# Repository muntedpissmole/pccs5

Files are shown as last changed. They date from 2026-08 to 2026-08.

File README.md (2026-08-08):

# The Pissmole Camper Control System

PCCS is a software and hardware solution for control of electrics and home automation in a caravan or camper trailer. It replaces a typical switch panel and gauges like water and battery levels with a modern touchscreen UI that provides control of dimmable lighting, one-touch activation of lighting scenes and automatic triggering of lights based on sunset/sunrise times and door or panel open and closes. The software runs on a Raspberry Pi 4 or 5. A PCB design for ordering the PCCS Core circuit board and 3D printable mount is provided in the `/kicad` folder.

Important information is displayed at a glance (full list and screenshots below). Internet can be distributed from a USB/Wi-Fi hotspot or Starlink through a downstream WAP. Networking services - NAT, DNS, DHCP and ad-filtering are provided by nftables and Pi-Hole. Instructions are provided for installing the UniFi OS server for management of WAP points if desired.

The UI is accessible from any device connected to the WiFi and can also be accessed remotely via something like a Cloudflare tunnel.

## Getting started

Start with [Wiring and Hardware](https://github.com/muntedpissmole/pccs5/wiki/Wiring-and-Hardware) to fabricate, mount and wire the PCCS Core PCB, then see [Software Installation](https://github.com/muntedpissmole/pccs5/wiki/Software-Installation) to install the PCCS via the guided installer.

Full instructions are in the [project wiki](https://github.com/muntedpissmole/pccs5/wiki/).

## System overview

A touchscreen in the kitchen or similar area shows the main user interface and is also reachable from phones or tablets on the LAN:

- Dimmable lighting sliders with red/white anti-bug mode and on/off buttons for non-dimmable loads (water, lighting, fridge circuits)
- Ambient lights that fade on as it gets dark
- One-touch lighting scenes
- Control of Sonos speakers
- Light/dark UI themes and an extensive settings page

## Display of Environmental information

- Water tank level
- Current temperature and fridge/freezer temperatures
- Current battery charge, voltage, current consumption, estimated power remaining and current/daily solar generation
- GPS coordinates, closest suburb, altitude, satellite quality, sunrise/sunset, and the day/evening/night timing that drives automation
- 4 Day weather forecast, humidity and expected overnight temperature if Internet is present
- Internet connection quality details
- What lights are on and what doors or panels are open
- Health status of connected hardware modules like solar or GPS

## Hardware architecture

- Raspberry Pi 4/5
- Dual ESP32-S3s for 16 channels of PWM dimming via MOSFETs
- u-blox NEO-M9N GPS for location data
- Victron SmartShunt and SmartSolar support for battery and solar monitoring
- WS281X addressable LED strip outputs
- 10A relays for non-dimmable loads like lighting circuits, floodlights and water pumps
- Reed switch inputs for door/panel sensing and triggering of lights
- 1-Wire bus for temperature sensors
- Water tank level sensor input
- Spare channels for everything for expansion

### PCCS Core

<table>
  <tr>
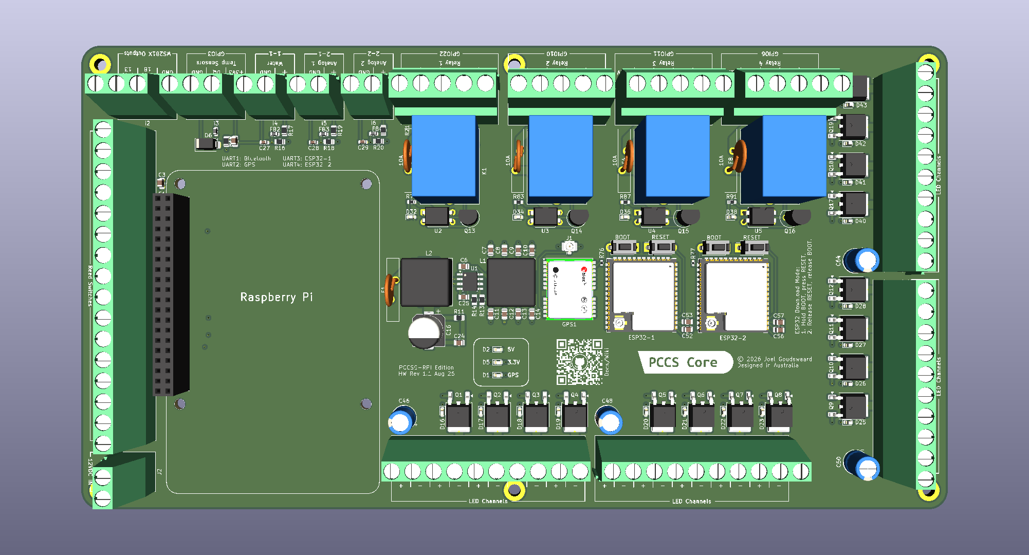
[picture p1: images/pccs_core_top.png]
PCCS Core — top, bare board
    <td align="center" width="50%"></td>
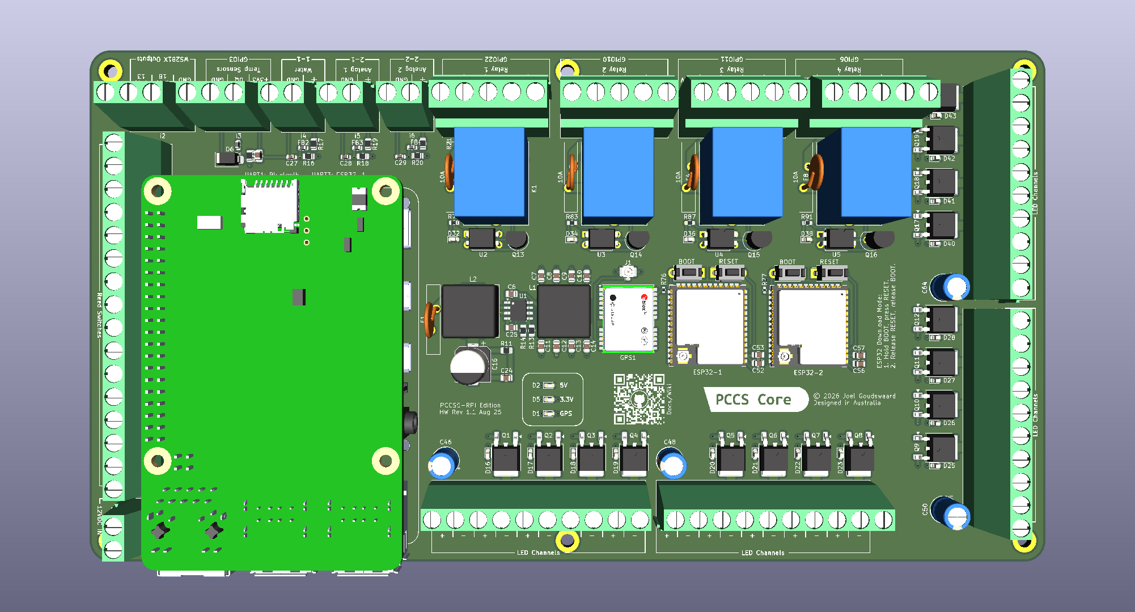
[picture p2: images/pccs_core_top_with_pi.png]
PCCS Core — top, with Raspberry Pi fitted
    <td align="center" width="50%"></td>
  </tr>
  <tr>
    <td align="center"><strong>Top (bare board)</strong></td>
    <td align="center"><strong>Top (with Raspberry Pi fitted)</strong></td>
  </tr>
  <tr>
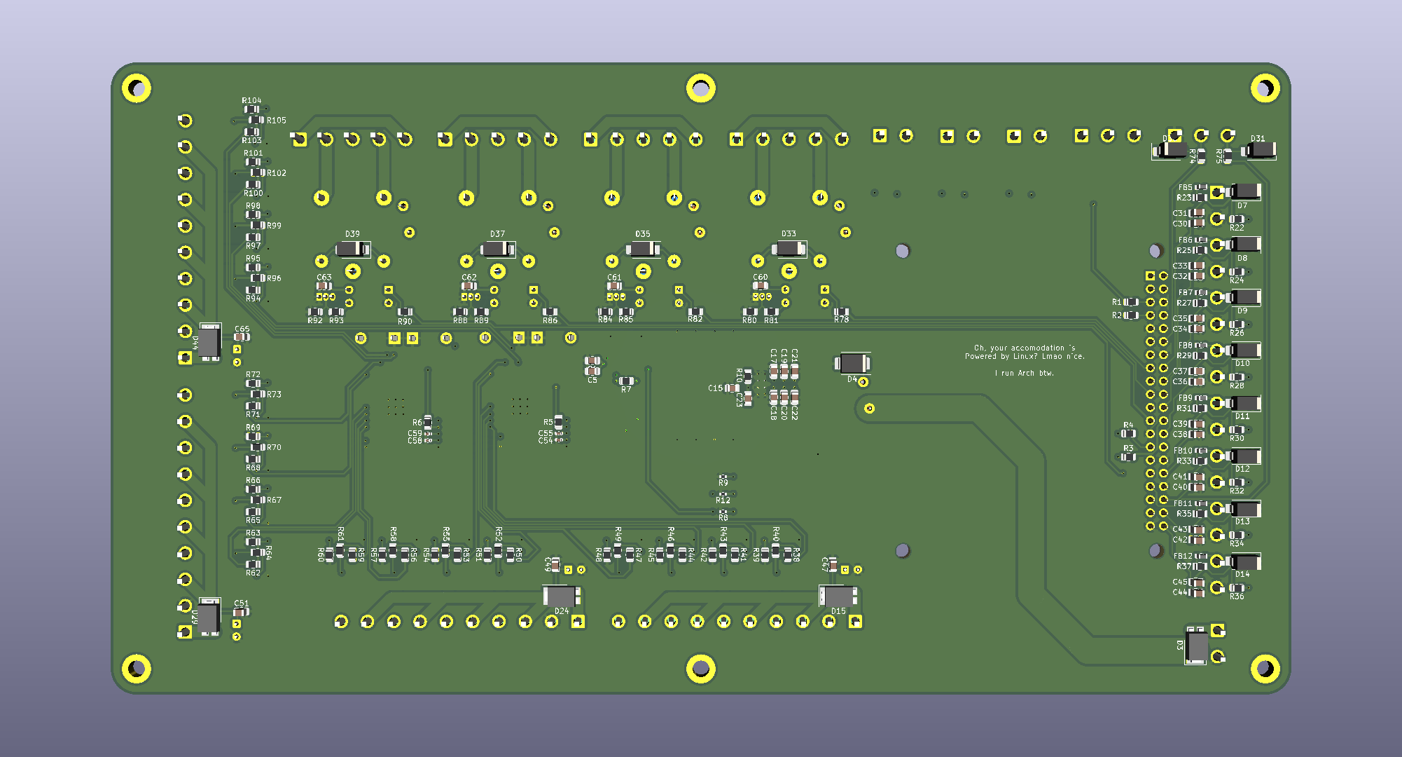
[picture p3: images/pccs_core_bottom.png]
PCCS Core — bottom
    <td align="center"></td>
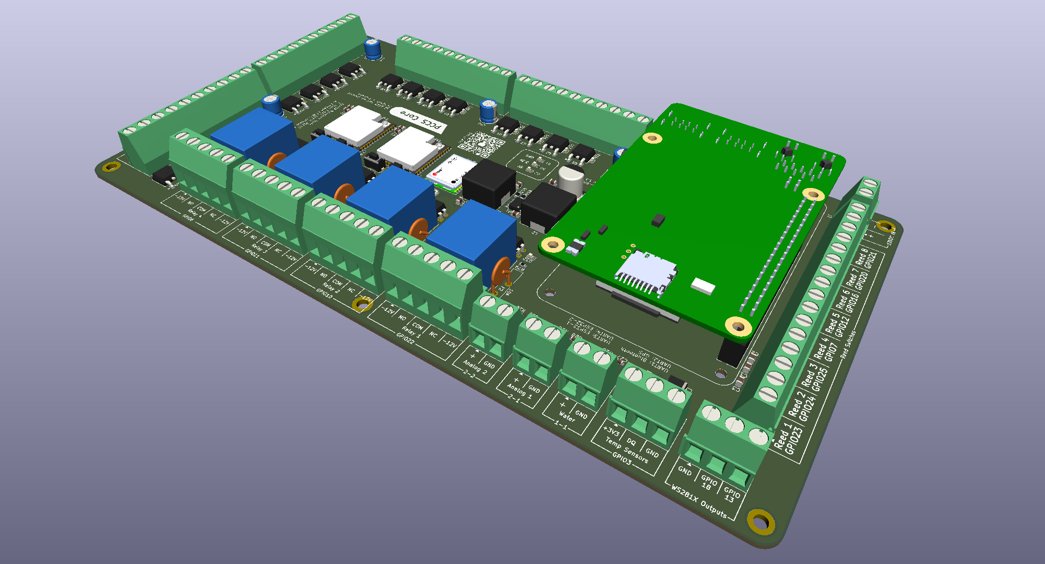
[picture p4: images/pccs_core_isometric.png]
PCCS Core — isometric view with Raspberry Pi fitted
    <td align="center"></td>
  </tr>
  <tr>
    <td align="center"><strong>Bottom</strong></td>
    <td align="center"><strong>Isometric (with Raspberry Pi fitted)</strong></td>
  </tr>
</table>

## User interface

The UI runs on touchscreens, tablets, and phones.

<table>
  <tr>
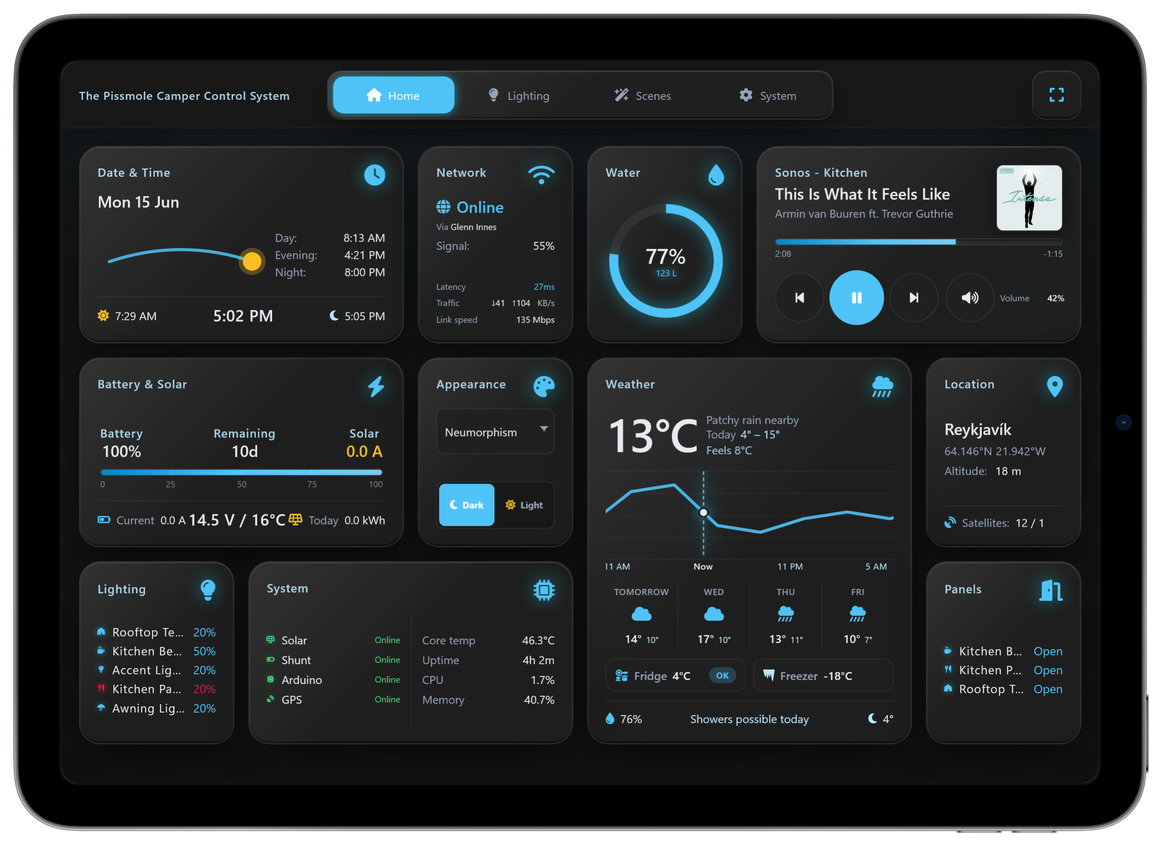
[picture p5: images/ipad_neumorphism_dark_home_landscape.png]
Neumorphism dark — iPad landscape
    <td align="center"></td>
  </tr>
  <tr>
    <td align="center"><strong>Neumorphism (Dark)</strong></td>
  </tr>
  <tr>
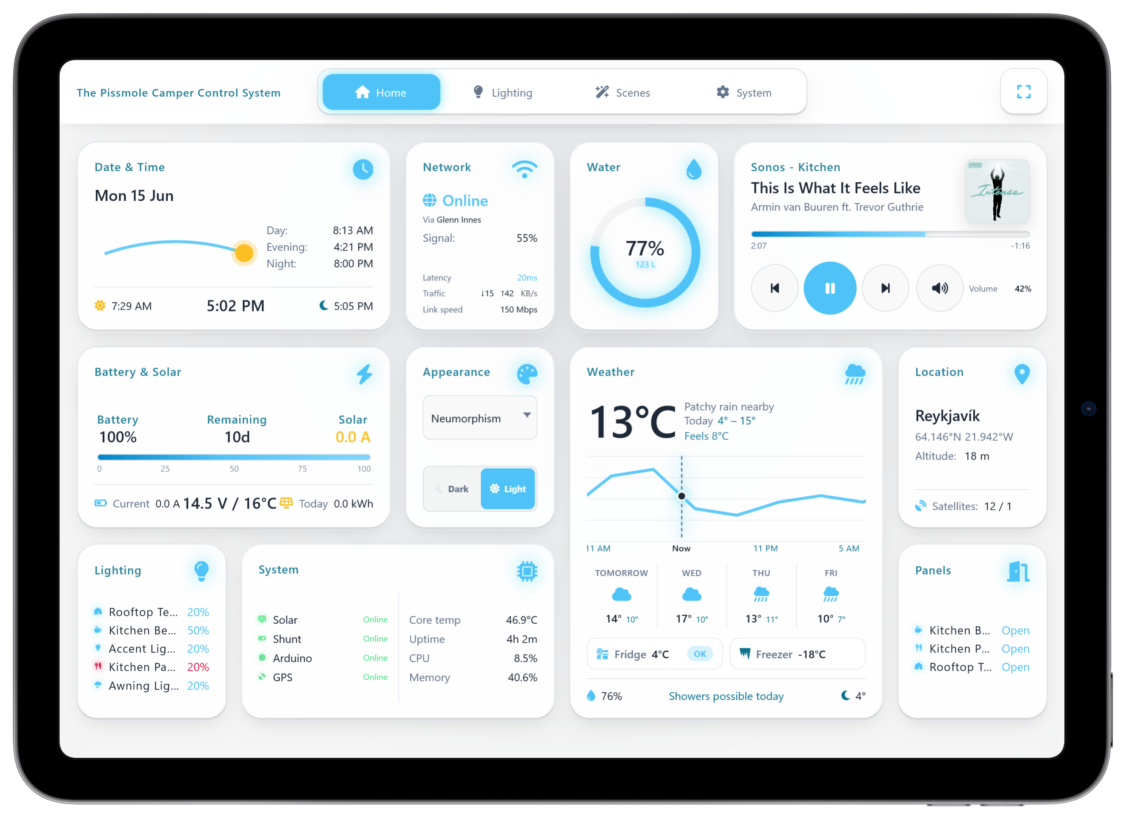
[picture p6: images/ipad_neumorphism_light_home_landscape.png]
Neumorphism light — iPad landscape
    <td align="center"></td>
  </tr>
  <tr>
    <td align="center"><strong>Neumorphism (Light)</strong></td>
  </tr>
  <tr>
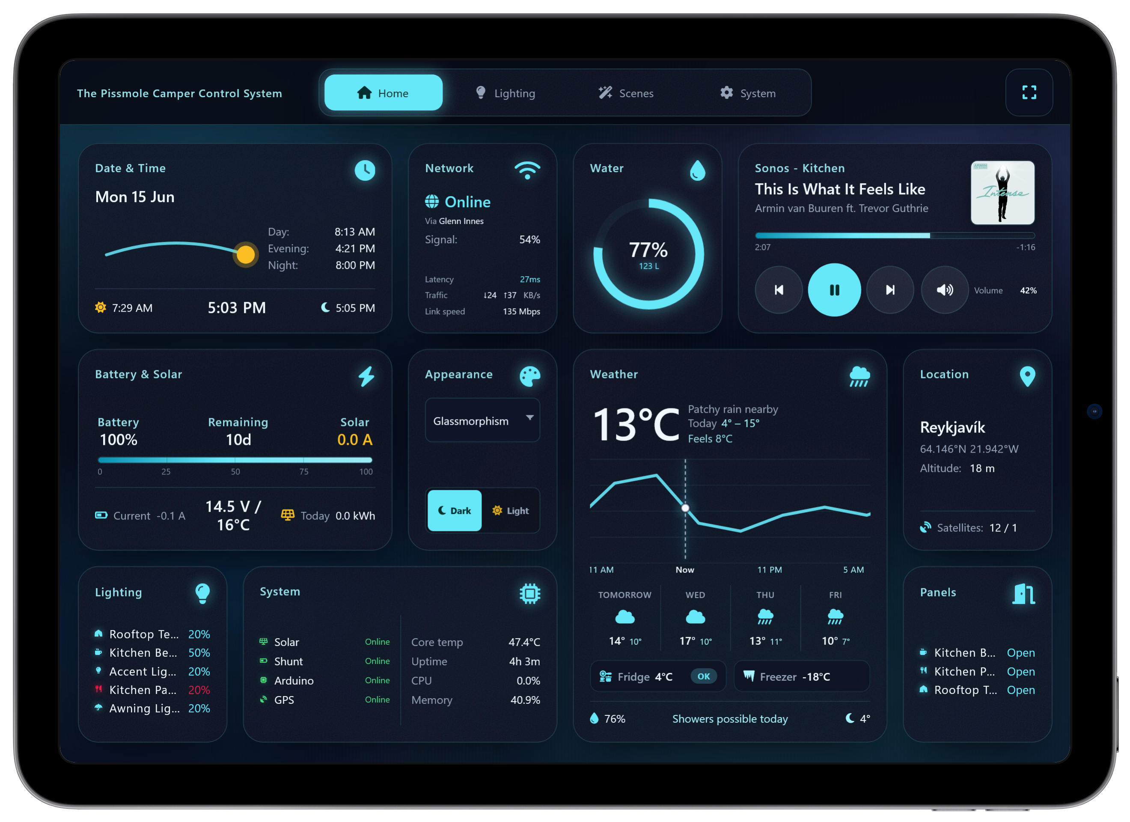
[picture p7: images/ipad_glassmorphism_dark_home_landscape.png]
Glassmorphism dark — iPad landscape
    <td align="center"></td>
  </tr>
  <tr>
    <td align="center"><strong>Glassmorphism (Dark)</strong></td>
  </tr>
  <tr>
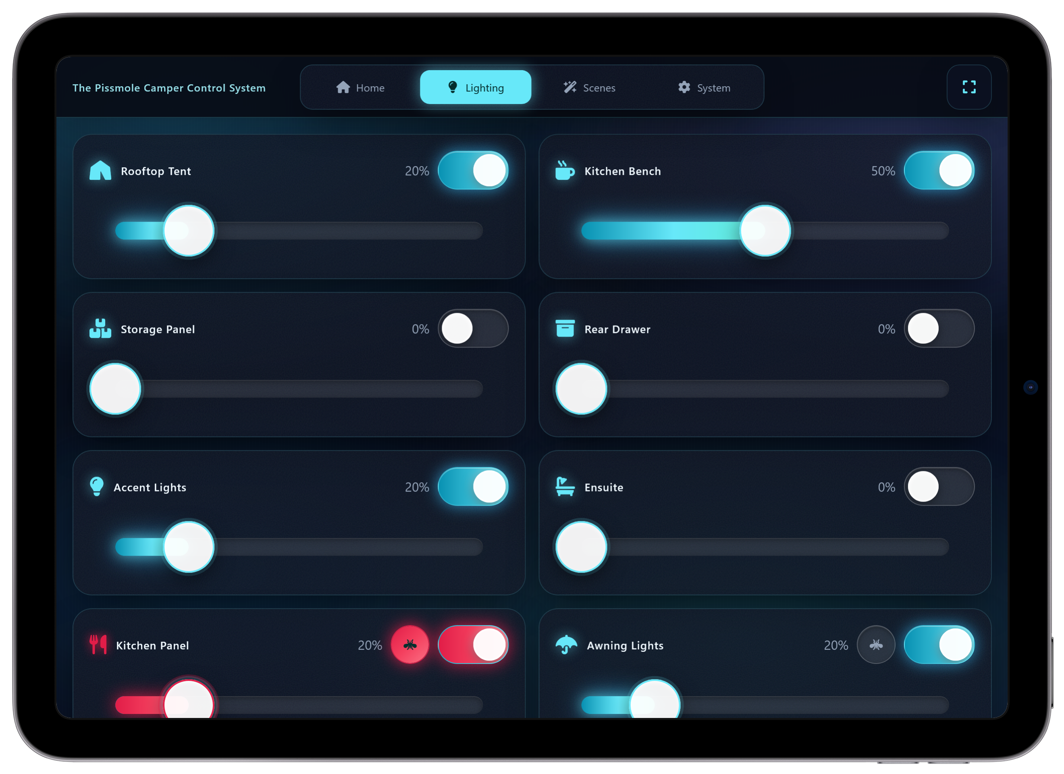
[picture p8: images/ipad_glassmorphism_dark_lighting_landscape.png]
Glassmorphism dark — iPad lighting
    <td align="center"></td>
  </tr>
  <tr>
    <td align="center"><strong>Glassmorphism (Dark) — Lighting</strong></td>
  </tr>
</table>

<table>
  <tr>
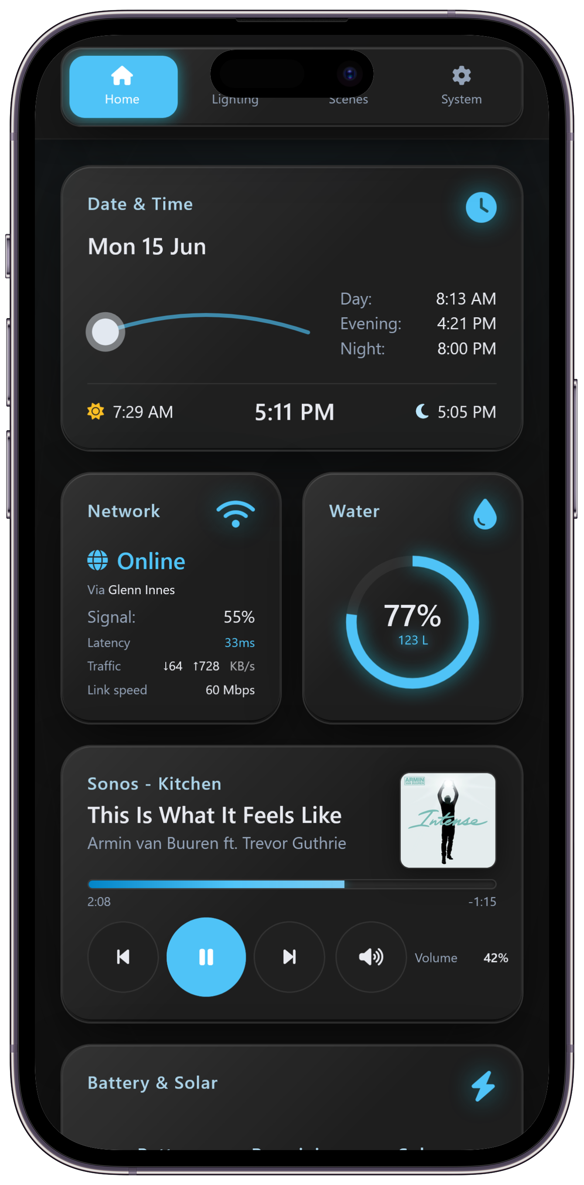
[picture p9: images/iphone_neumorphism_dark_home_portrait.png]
Neumorphism dark — iPhone portrait
    <td align="center" width="50%"></td>
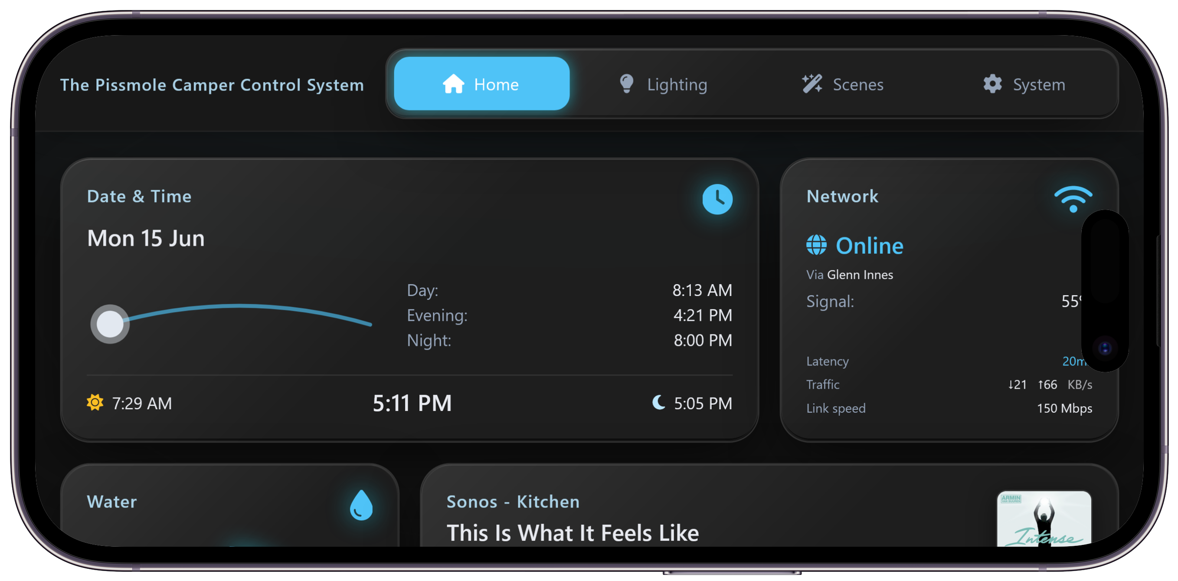
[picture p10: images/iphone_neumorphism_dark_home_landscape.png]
Neumorphism dark — iPhone landscape
    <td align="center" width="50%"></td>
  </tr>
  <tr>
    <td align="center"><strong>Neumorphism (Dark) — iPhone Portrait</strong></td>
    <td align="center"><strong>Neumorphism (Dark) — iPhone Landscape</strong></td>
  </tr>
</table>

<details>
<summary><h3>Additional themes (click to expand)</h3></summary>

<table>
  <tr>
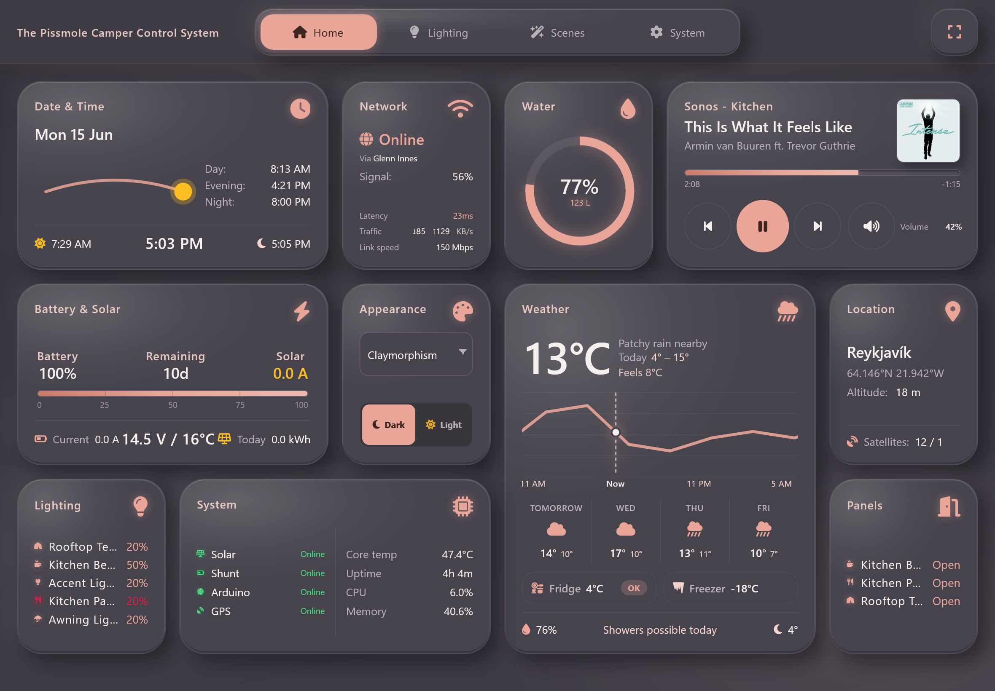
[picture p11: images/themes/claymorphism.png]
Claymorphism
    <td align="center" width="50%"></td>
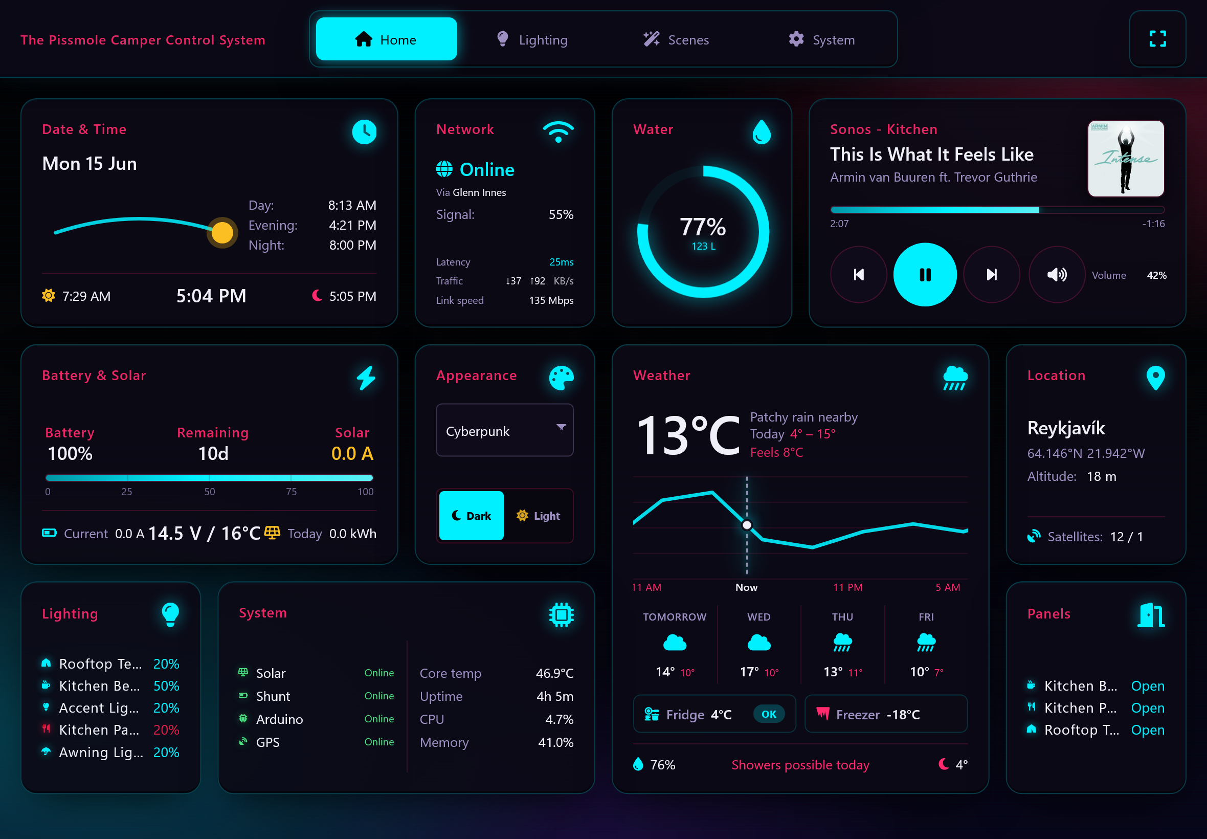
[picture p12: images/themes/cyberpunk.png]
Cyberpunk
    <td align="center" width="50%"></td>
  </tr>
  <tr>
    <td align="center"><strong>Claymorphism</strong><br></td>
    <td align="center"><strong>Cyberpunk</strong><br></td>
  </tr>
  <tr>
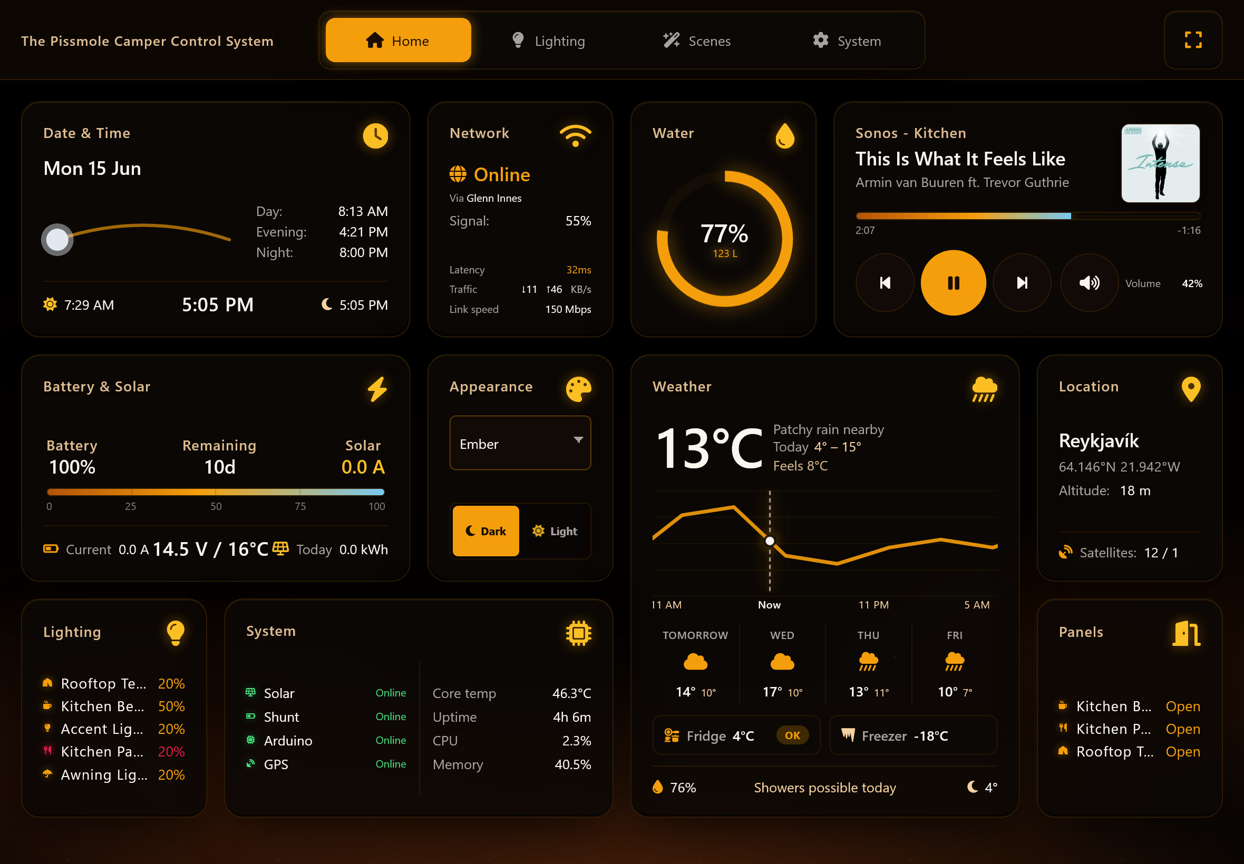
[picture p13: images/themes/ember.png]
Ember
    <td align="center"></td>
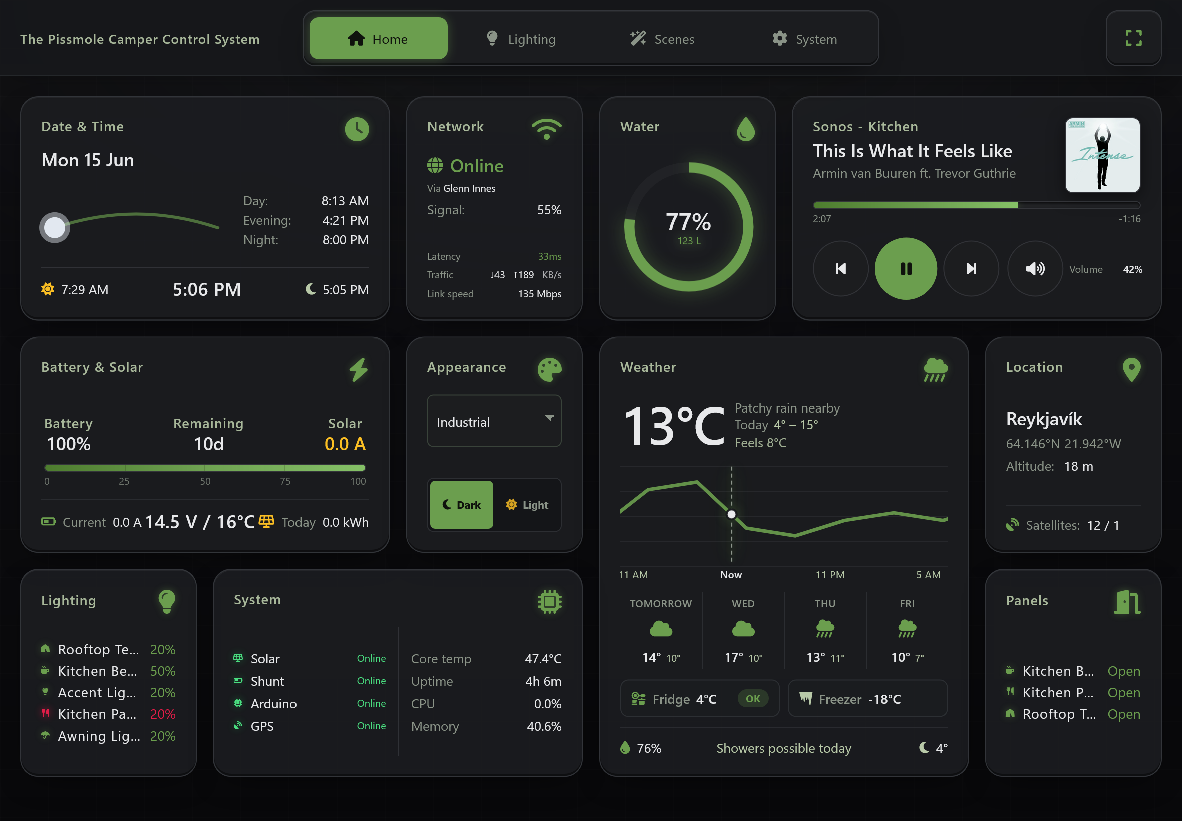
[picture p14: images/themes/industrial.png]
Industrial
    <td align="center"></td>
  </tr>
  <tr>
    <td align="center"><strong>Ember</strong><br></td>
    <td align="center"><strong>Industrial</strong><br></td>
  </tr>
  <tr>
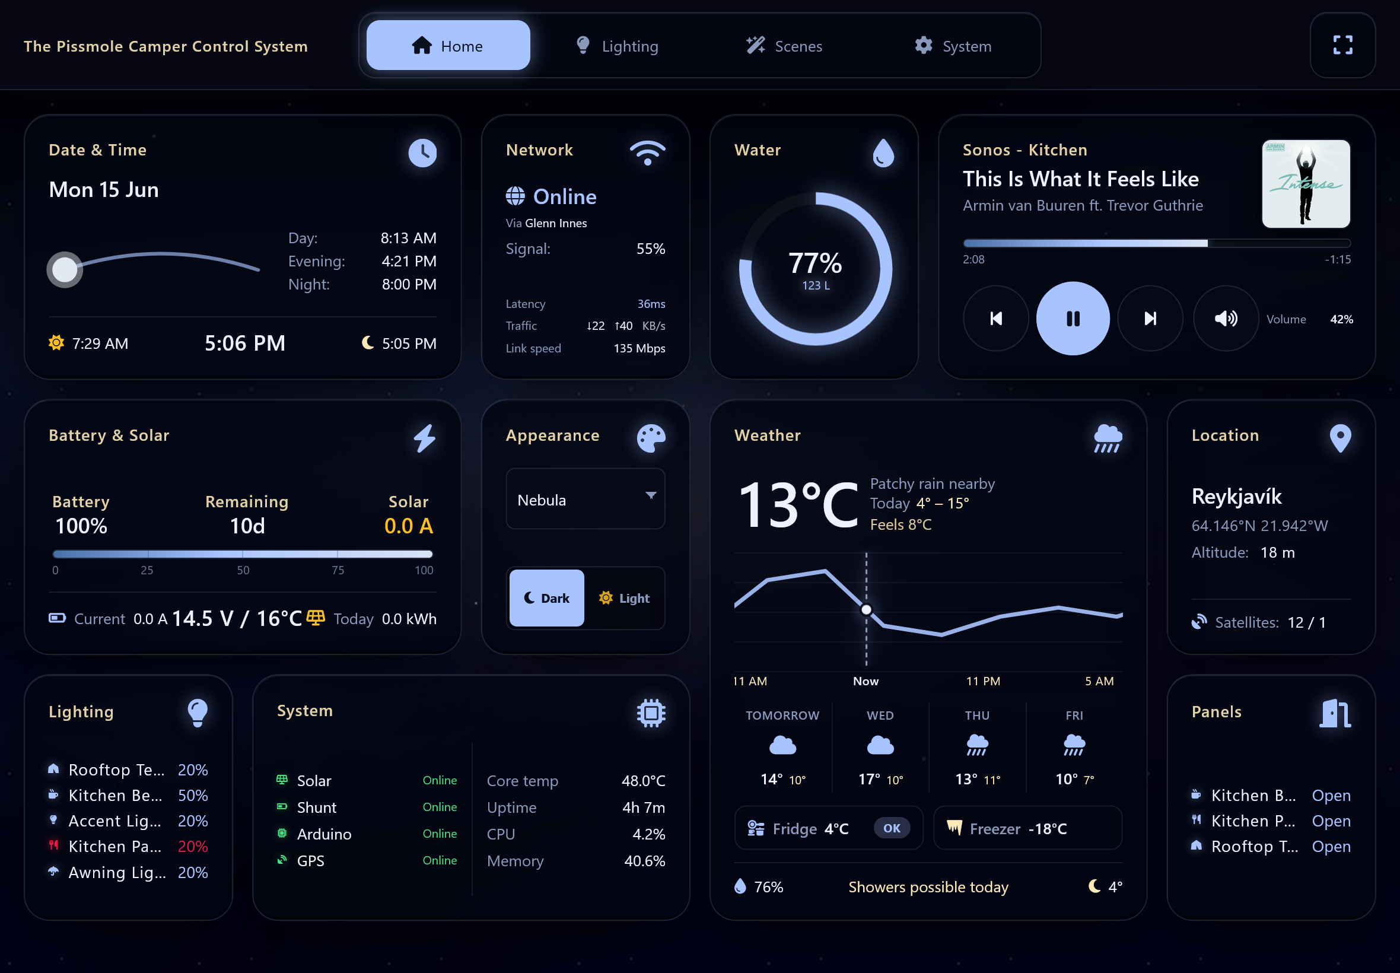
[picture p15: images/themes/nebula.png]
Nebula
    <td align="center"></td>
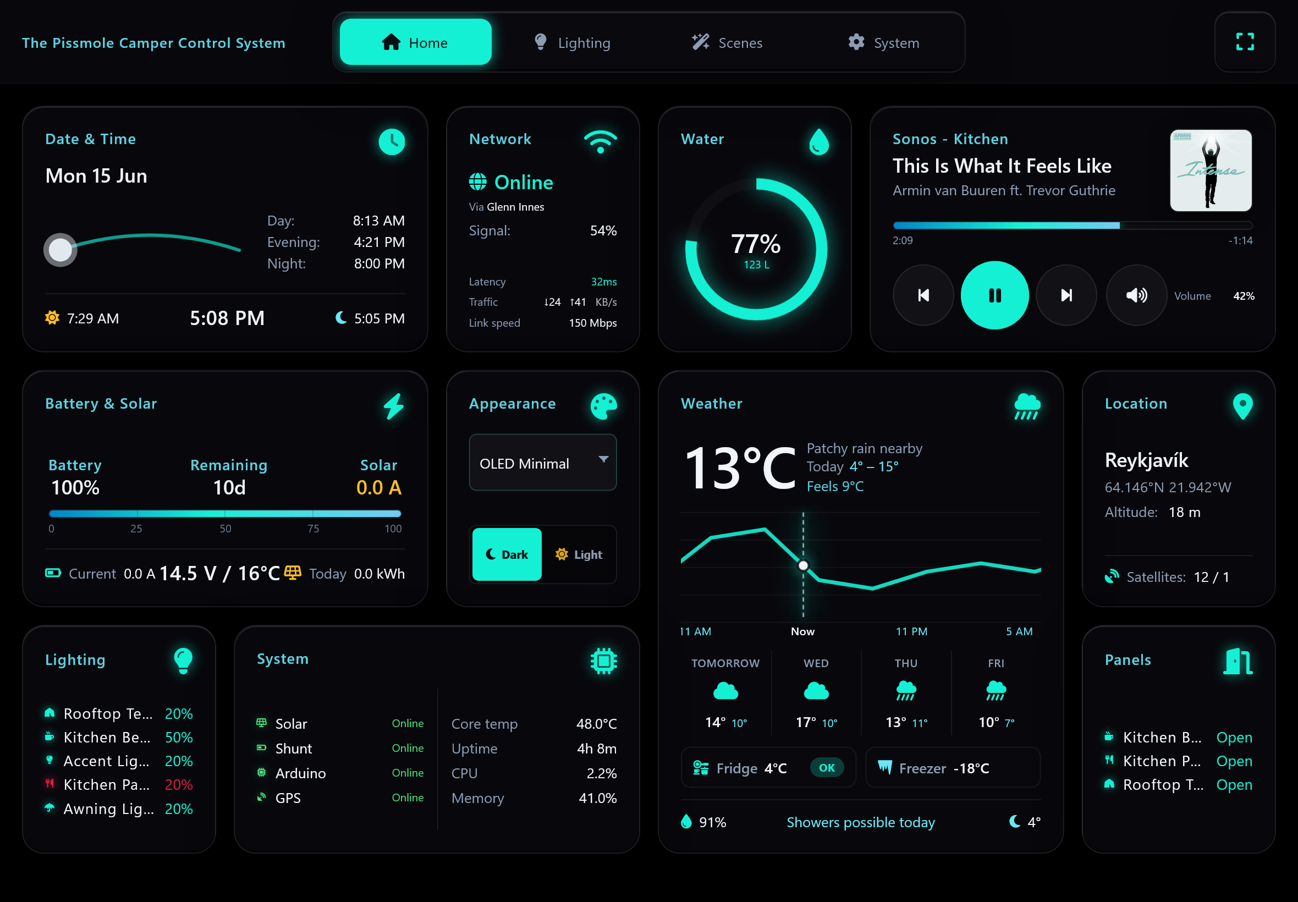
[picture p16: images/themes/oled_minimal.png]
OLED Minimal
    <td align="center"></td>
  </tr>
  <tr>
    <td align="center"><strong>Nebula</strong><br></td>
    <td align="center"><strong>OLED Minimal</strong><br></td>
  </tr>
  <tr>
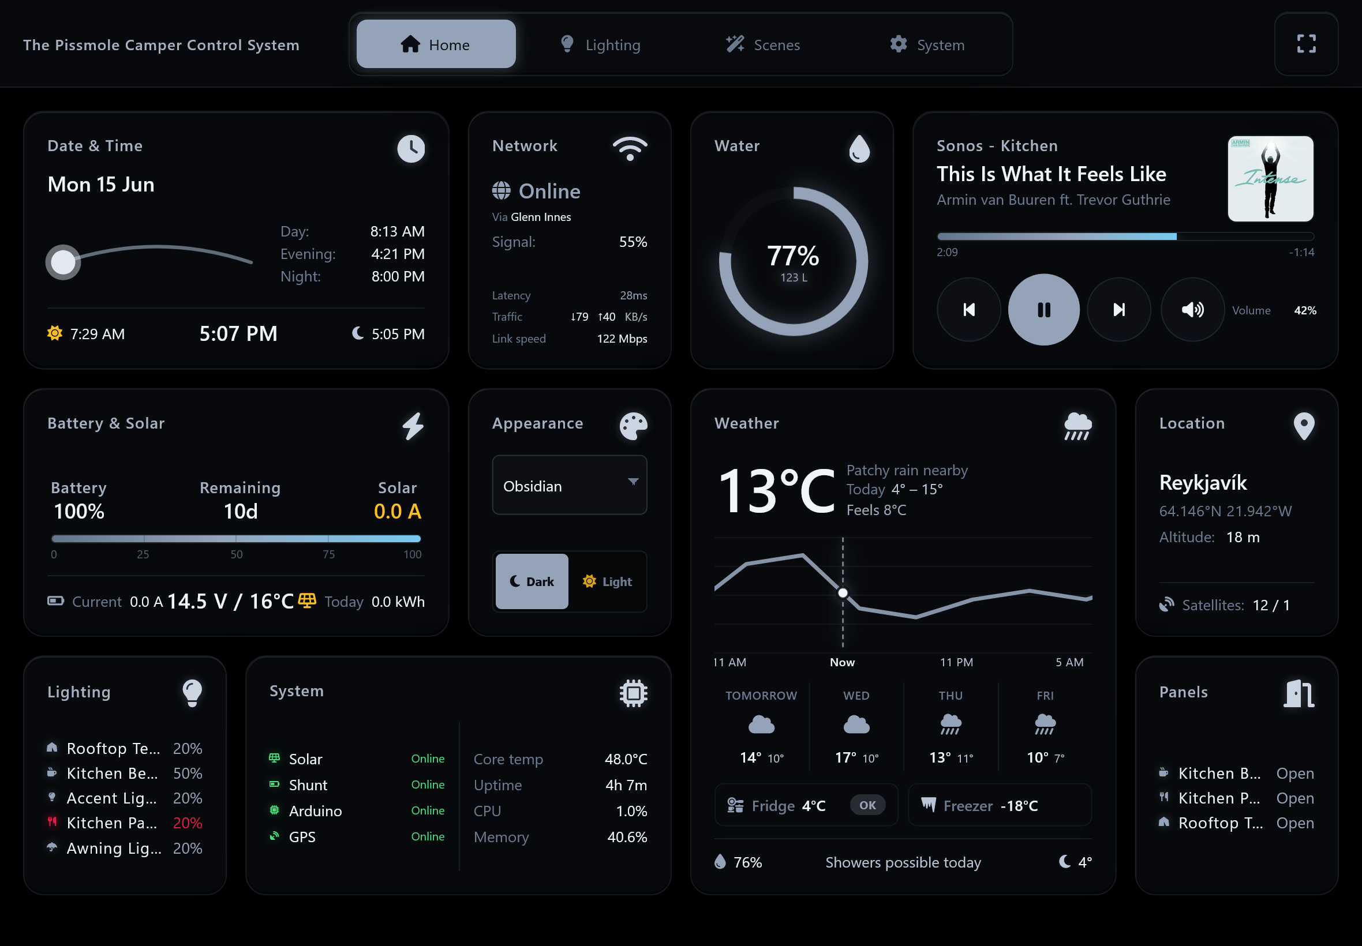
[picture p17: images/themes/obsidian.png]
Obsidian
    <td align="center"></td>
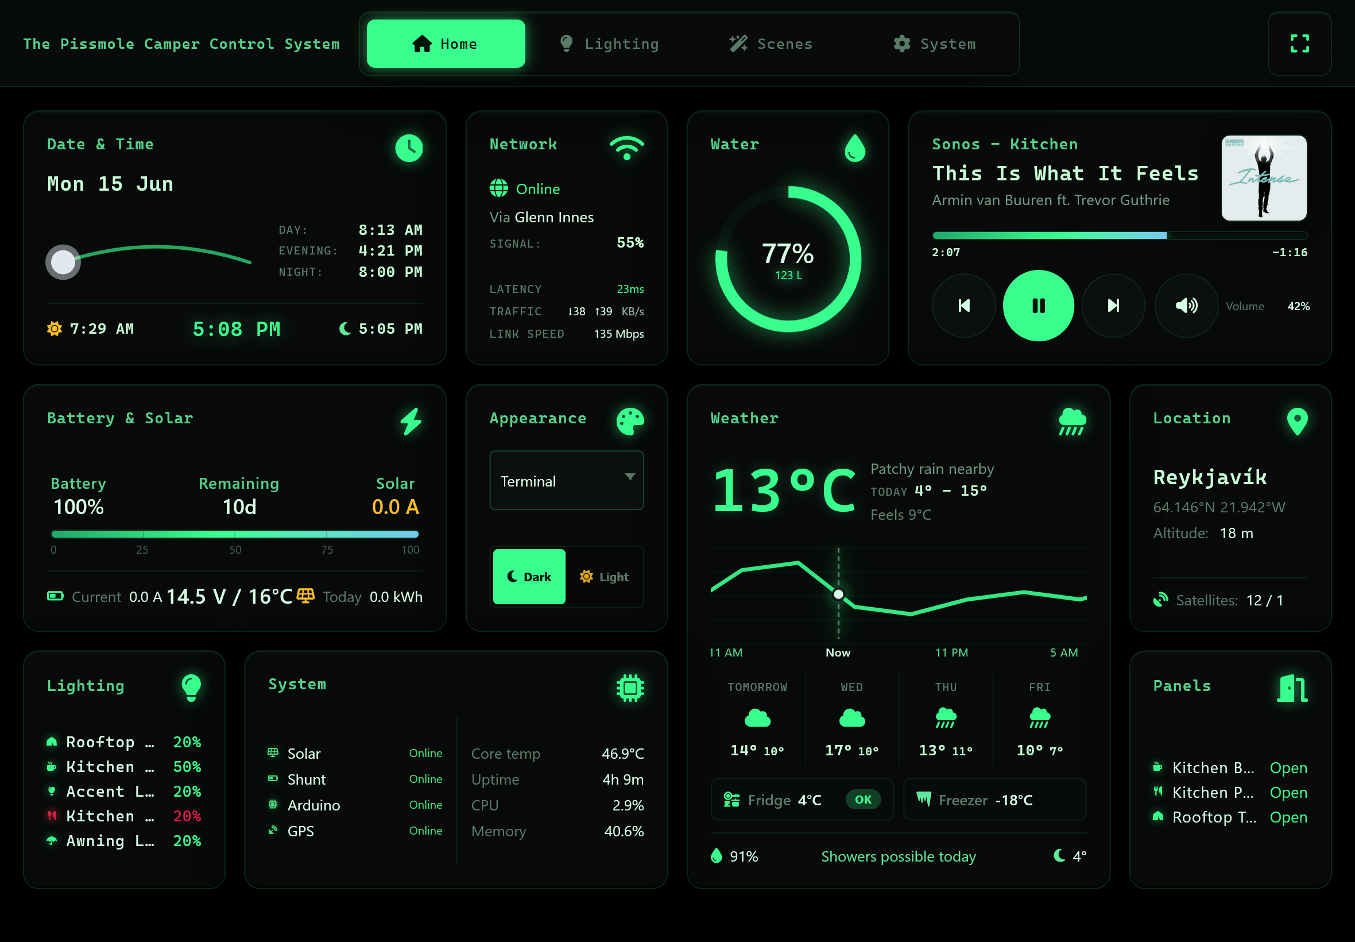
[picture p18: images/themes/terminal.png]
Terminal
    <td align="center"></td>
  </tr>
  <tr>
    <td align="center"><strong>Obsidian</strong><br></td>
    <td align="center"><strong>Terminal</strong><br></td>
  </tr>
  <tr>
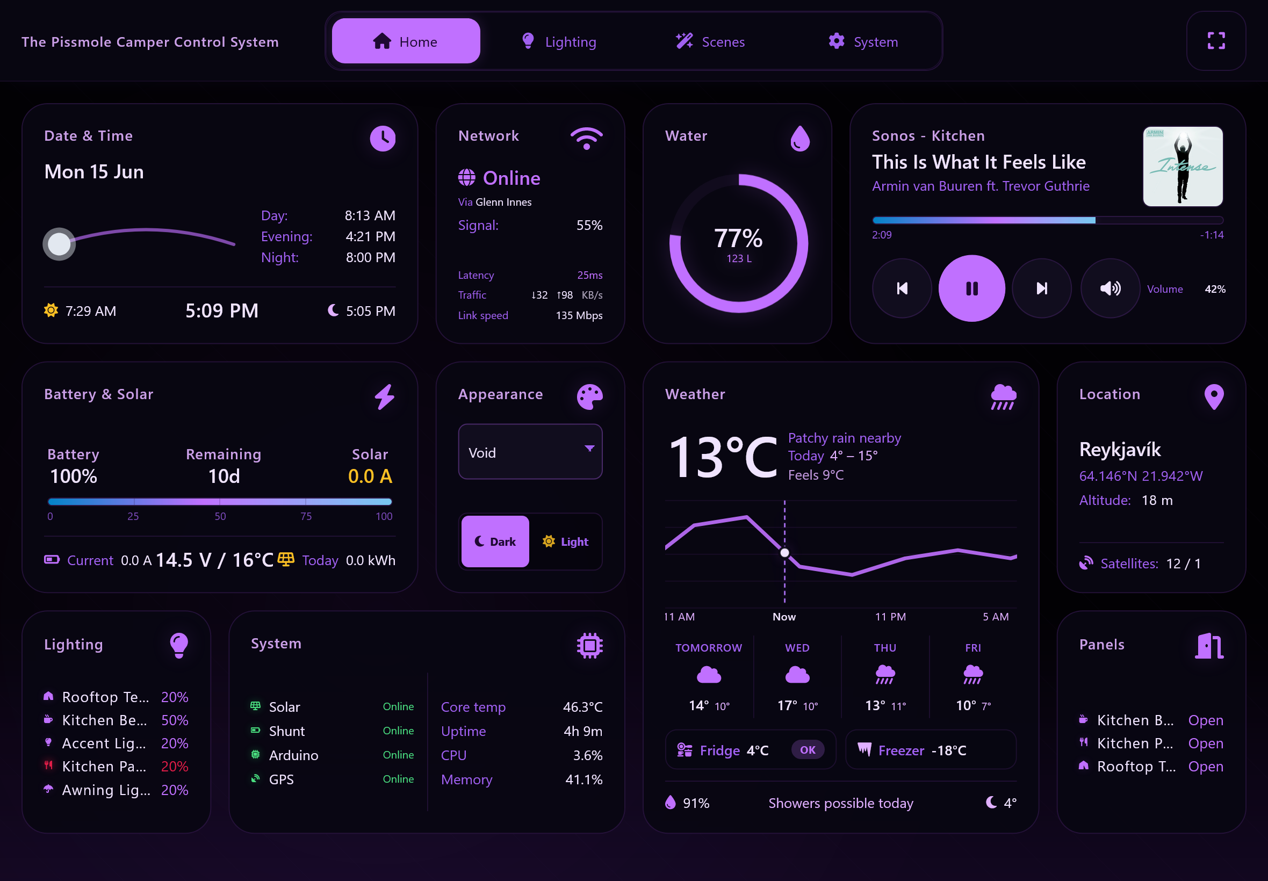
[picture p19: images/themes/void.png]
Void
    <td align="center" colspan="2"></td>
  </tr>
  <tr>
    <td align="center" colspan="2"><strong>Void</strong><br></td>
  </tr>
</table>

More examples in the [`/images`](images/) folder.

</details>

---

## Documentation

Wiring, installation, configuration, and optional packages are on the **[project wiki](https://github.com/muntedpissmole/pccs5/wiki)**.

| Topic | Wiki page |
|---|---|
| PCCS4 vs PCCS5 | [Differences between PCCS4 and PCCS5](https://github.com/muntedpissmole/pccs5/wiki/Differences-between-PCCS4-and-PCCS5) |
| Wiring and hardware | [Wiring and Hardware](https://github.com/muntedpissmole/pccs5/wiki/Wiring-and-Hardware) |
| Software Installation | [Software Installation](https://github.com/muntedpissmole/pccs5/wiki/Software-Installation) |
| Software Configuration | [Software Configuration](https://github.com/muntedpissmole/pccs5/wiki/Software-Configuration) |
| Victron setup | [Victron Setup](https://github.com/muntedpissmole/pccs5/wiki/Victron-Setup) |
| Toast system | [Toast System](https://github.com/muntedpissmole/pccs5/wiki/Toast-System) |
| UniFi OS Server | [UniFi OS Server](https://github.com/muntedpissmole/pccs5/wiki/UniFi-OS-Server) |
| Pi-hole | [Pi-hole](https://github.com/muntedpissmole/pccs5/wiki/Pi-hole) |

---

## License

Licensed under the [MIT License](LICENSE).

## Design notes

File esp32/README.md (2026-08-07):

# PCCS5 ESP32-S3 firmware

ESP32-S3-WROOM-1U firmware for the two lighting/analog MCUs.

Host protocol (UART1, 115200 8N1): `SET` / `RAMP` / `GET` / `ANALOG` / `GETVCC` / `GETALL`.

| Sketch | Role | Pi UART | ESP host UART | PWM GPIOs | Analog GPIOs |
|---|---|---|---|---|---|
| `esp32_1/` | ESP32-1 | `uart3` → `/dev/ttyAMA2` (Pi GPIO 4/5) | GPIO 17 RX / 18 TX | 4–11 | 1 (water) |
| `esp32_2/` | ESP32-2 | `uart4` → `/dev/ttyAMA3` (Pi GPIO 8/9) | GPIO 17 RX / 18 TX | 4–11 | 1, 2 |

Shared core: `PccsEspFirmware.h` (copied into each sketch folder).

## Build / flash

- Chip: **ESP32-S3** / **ESP32-S3-WROOM-1U**
- Upload over the module’s programming USB interface (not the Pi host UART)

```bash
arduino-cli core update-index
arduino-cli core install esp32:esp32

arduino-cli compile --fqbn esp32:esp32:esp32s3 esp32/esp32_1
arduino-cli upload -p /dev/ttyACM0 --fqbn esp32:esp32:esp32s3 esp32/esp32_1

arduino-cli compile --fqbn esp32:esp32:esp32s3 esp32/esp32_2
arduino-cli upload -p /dev/ttyACM0 --fqbn esp32:esp32:esp32s3 esp32/esp32_2
```

## ADC / water level

- 12-bit reads (0–4095), 64-sample average — matches `water_adc_max = 4095` on the Pi
- `GETVCC` returns `3300` (mV of the 3V3 rail for the 150 Ω pull-ups)
- Water sender on ESP32-1 GPIO 1: empty ~240 Ω, full ~33 Ω (`config/pccs.conf` `[sensors]`)

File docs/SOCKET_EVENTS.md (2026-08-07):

# PCCS5 Socket Event Contract

This document defines every Socket.IO event used by the lighting backend in this pass.

## Offline overlay

When Socket.IO disconnects (or fails to load), `#offline-overlay` appears after 800ms and blocks interaction until reconnect. Implemented in `offline-overlay.js` + `socket-client.js`.

## Client → Server

### `light_change`

User moved a dimmer slider or toggled a dimmer pill.

```json
{ "name": "kitchen_bench", "brightness": 65 }
```

RGB bug lights include mode:

```json
{ "name": "kitchen_panel", "brightness": 55, "mode": "red" }
```

- `name` must be in `compiled.light_names`
- `brightness` clamped 0–100 server-side
- `mode` only applied for RGB lights

**HTTP fallback:** `POST /api/light` with the same JSON body.

### `relay_change`

User toggled a relay control (socket only — no HTTP fallback).

```json
{ "name": "floodlights", "on": true }
```

Relays use `expires: manual` — they persist through scenes, reed changes, and phase changes until toggled again.

### `get_reeds`

Request effective reed states. Server replies with `reed_update`.

### `set_scene`

Activate a lighting scene (one-shot reconcile with ramp).

```json
{ "scene": "bedtime" }
```

**HTTP fallback:** `POST /api/scene` with the same JSON body.

### `force_phase`

Lock or clear phase override.

```json
{ "phase": "Evening" }
```

Clear: `{ "phase": null }`

### `force_reed`

Diagnostics override (also affects main UI effective states).

```json
{ "name": "rooftop_tent", "closed": true }
```

Clear force: `{ "name": "rooftop_tent", "closed": null }`

## Server → Client

### `lights_config`

Sent on `connect`. Ordered list of UI controls from `pccs.conf`:

```json
[
  { "name": "rooftop_tent", "label": "Rooftop Tent", "type": "dimmer", "icon": "fa-tent", "has_mode": false, "order": 10 }
]
```

`type` is `dimmer` or `relay`.

### `state_update`

Authoritative light/relay levels after reconcile.

```json
{
  "kitchen_bench": 65,
  "kitchen_panel": 55,
  "kitchen_panel_mode": "white",
  "floodlights": 1
}
```

- Dimmers: 0–100 integer brightness
- Relays: truthy/falsey on state
- RGB lights: `{name}_mode` key with `white` or `red`

### `reeds_config`

Sent on `connect`. Reed metadata for the system tile:

```json
[{ "name": "kitchen_panel", "label": "Kitchen Panel", "icon": "fa-utensils", "order": 10 }]
```

### `reed_update` (main UI)

Effective reed states — hardware merged with operator forces.

```json
{ "states": { "rooftop_tent": true, "kitchen_bench": false } }
```

`true` = closed (secure), `false` = open.

**Main UI rule:** clients must not guess forced vs raw. Use this event only.

### `reed_diag_update` (diagnostics — future tile)

Raw hardware + force metadata. Not consumed by the lighting tab yet.

```json
{
  "states": { "rooftop_tent": true },
  "forced": { "kitchen_bench": false }
}
```

### `phase_update` (main UI)

```json
{ "phase": "evening", "day_start": "06:12", "evening_start": "18:45", "night_start": "21:30" }
```

### `gps_update`

Full GPS telemetry from `modules/gps` (also drives home location tile).

```json
{
  "fix_quality": 2,
  "satellites": 9,
  "latitude": -37.191,
  "longitude": 145.711,
  "suburb": "Alexandra",
  "hardware_missing": false
}
```

### `sensor_update`

Water tank and 1-wire temperatures.

```json
{
  "water_percent": 68,
  "outside_temp_c": 12.4,
  "fridge_temp_c": null,
  "temp_valid": true
}
```

### `set_gps_simulation`

Diagnostics: force no-fix mode.

```json
{ "no_fix": true }
```

### `phase_diag_update` (diagnostics)

```json
{ "forced": false }
```

`forced: true` when operator has locked phase via diag controls.

## REST

| Route | Purpose |
|---|---|
| `POST /api/light` | HTTP fallback for `light_change` |
| `GET /api/scenes` | Scene list for Scenes tab |
| `POST /api/scene` | HTTP fallback for `set_scene` |
| `GET /api/reeds` | Reed labels/icons for system tile |
| `GET /api/explain` | Policy snapshot: sources, desired vs observed, drift |

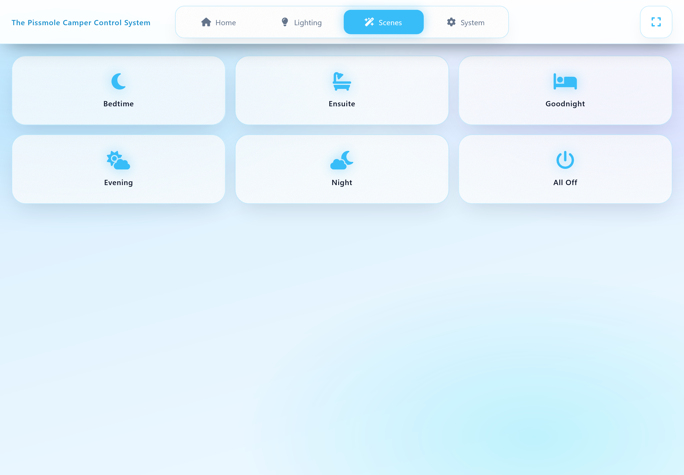
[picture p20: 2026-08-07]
images/themes/Glassmorphism/Screen Shot 2026-06-15 at 17.03.17.png

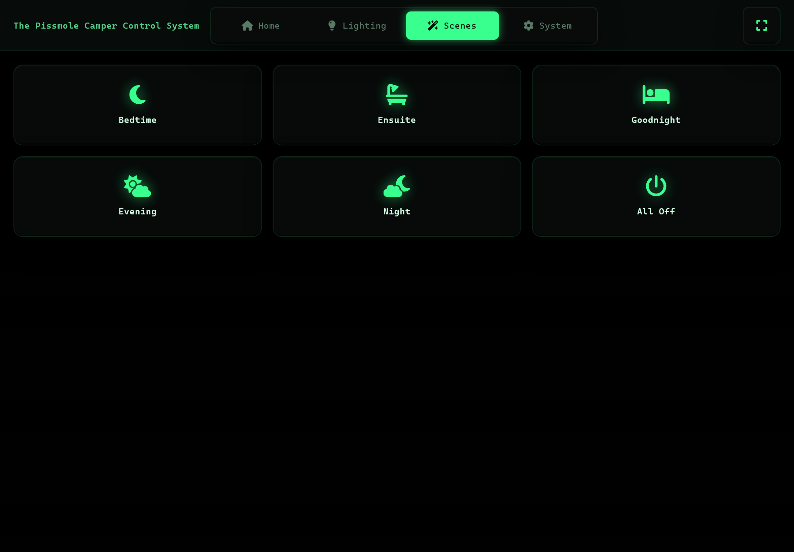
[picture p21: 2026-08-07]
images/themes/Terminal/Screen Shot 2026-06-15 at 17.08.59.png

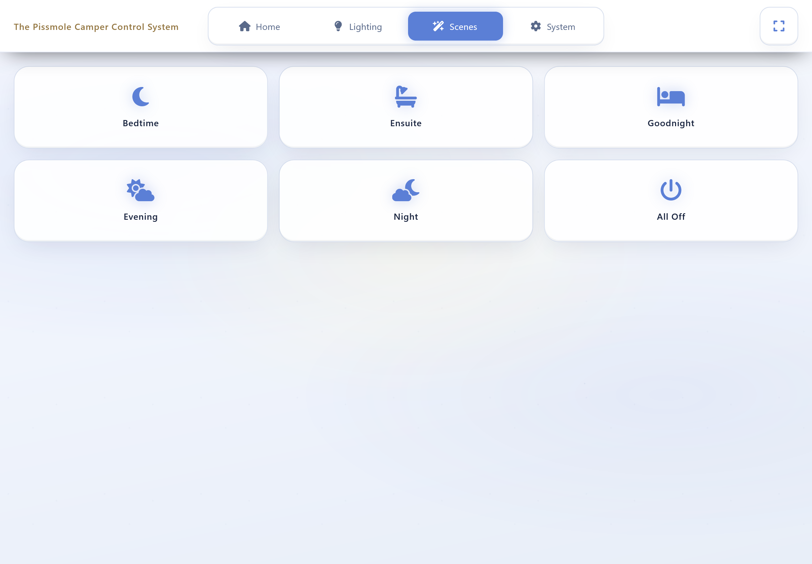
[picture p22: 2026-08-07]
images/themes/Nebula/Screen Shot 2026-06-15 at 17.06.58.png

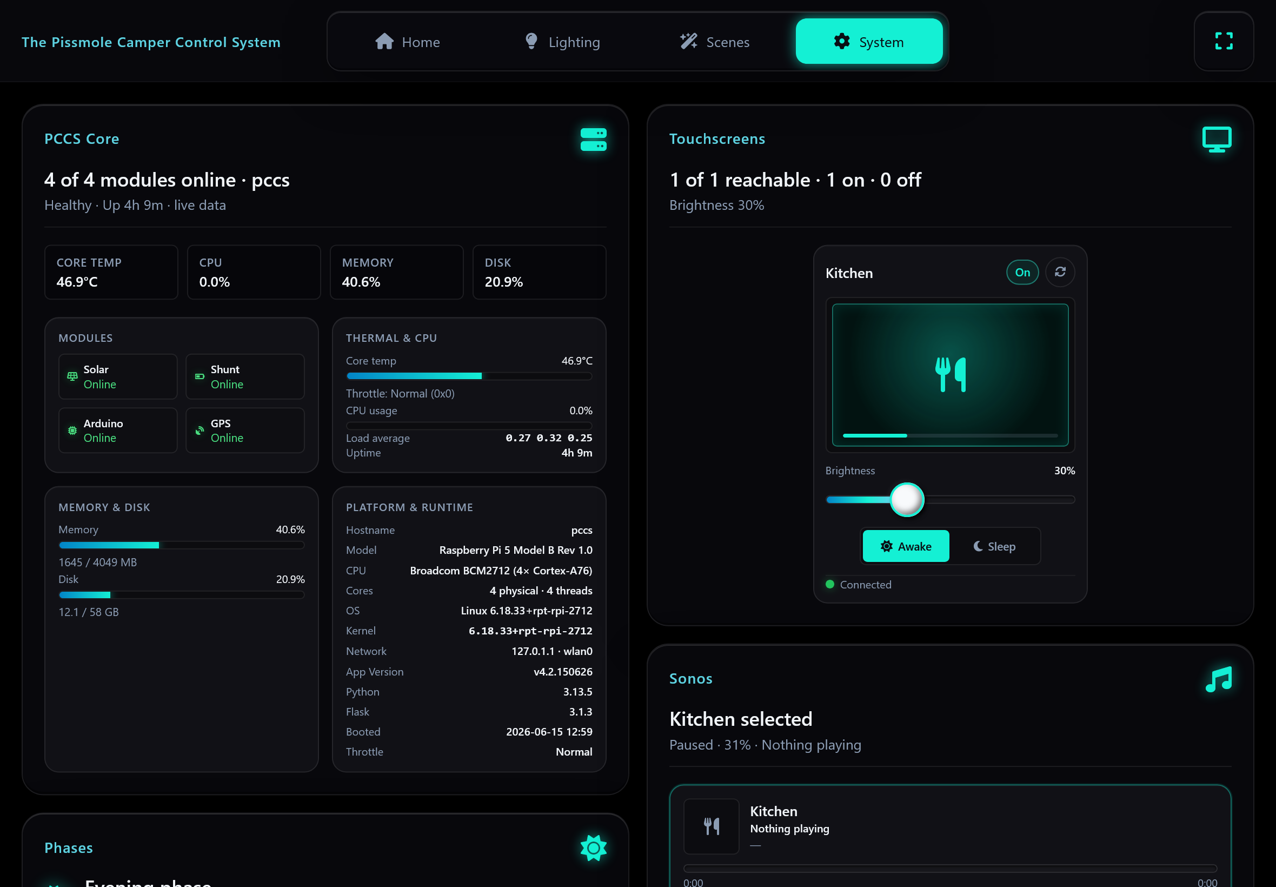
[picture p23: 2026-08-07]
images/themes/OLED Minimal/Screen Shot 2026-06-15 at 17.08.28.png

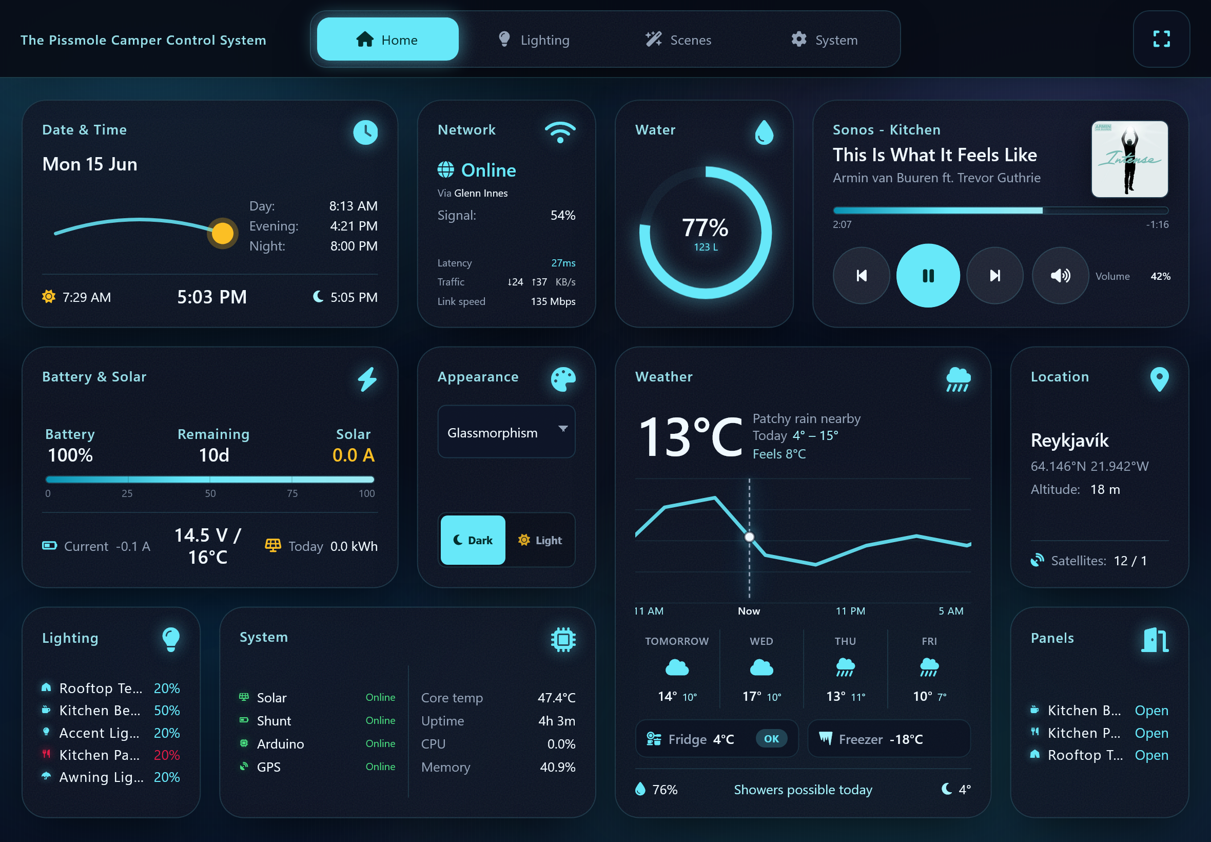
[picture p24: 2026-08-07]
images/themes/Glassmorphism/Screen Shot 2026-06-15 at 17.03.06.png

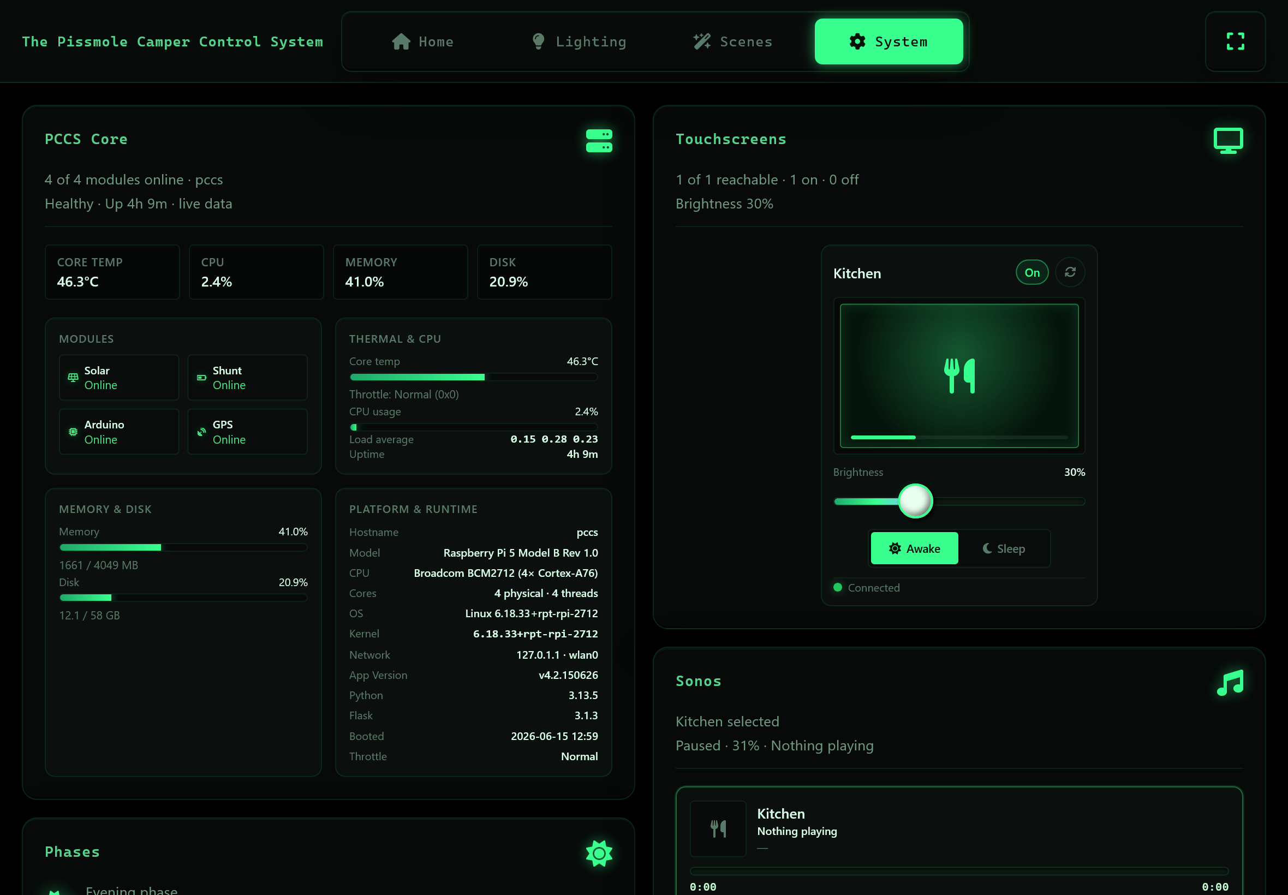
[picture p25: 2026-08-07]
images/themes/Terminal/Screen Shot 2026-06-15 at 17.09.05.png

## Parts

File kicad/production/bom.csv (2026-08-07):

Designator | Footprint | Quantity | Value | LCSC Part #
C1, C17 | 0805 | 2 | 10uF | C15850
C10, C11, C12, C13, C14, C19, C20, C21, C22, C4, C52, C56, C7, C8, C9 | 0805 | 15 | 22uF | C86816
C15 | 0805 | 1 | 2.7nF | C113859
C16 | CP_Elec_8x10 | 1 | 220uF | C165536
C18, C2, C26, C31, C33, C35, C37, C39, C41, C43, C45, C47, C49, C51, C60, C61, C62, C63, C65 | 0805 | 19 | 100nF | C49678
C23 | 0805 | 1 | 33pF | C17342103
C24 | 0805 | 1 | 100uF | C141660
C25 | 0805 | 1 | 10nF | C237168
C27, C28, C29 | 0603 | 3 | 100nF | C1590
C3 | 0805 | 1 | 47uF | C380345
C30, C32, C34, C36, C38, C40, C42, C44 | 0805 | 8 | 1uF | C91185
C46, C48, C50, C64 | CP_Radial_D6.3mm_P2.50mm | 4 | 100uF | C44587
C5, C53, C57, C6 | 0805 | 4 | 0.1uF | C86041
C54, C55, C58, C59 | 0402 | 4 | 100nF | C60474
D1 | 0603 | 1 | GPS | C2286
D10, D11, D12, D13, D14, D6, D7, D8, D9 | D_SMA | 9 | SMAJ3.3CA | C18199545
D15, D24, D29, D3, D44 | D_PowerDI-5 | 5 | ~ | C2759901
D16, D19, D20, D21, D22, D23, D25, D28, D40, D41, D42, D43 | 0603 | 12 | White | C2290
D17, D26 | 0603 | 2 | Red | C2286
D18, D27 | 0603 | 2 | Green | C12065
D2 | 0603 | 1 | 5V | C2286
D30, D31 | D_SMA | 2 | SMAJ5.0CA | C78402
D32, D34, D36, D38 | 0603 | 4 | Blue | C2288
D33, D35, D37, D39 | D_SMA | 4 | 1N4007 | C64915
D4 | D_SMB | 1 | SMAJ18A/TR13 | C571369
D5 | 0603 | 1 | 3.3V | C2286
ESP32-1, ESP32-2 | ESP32-S3-WROOM-1U | 2 | ESP32-S3-WROOM-1 | C3013946
F1, F2, F3, F4, F5 | Fuse_Bourns_MF-RG1000 | 5 | 10A | C14767
FB1, FB10, FB11, FB12, FB2, FB3, FB4, FB5, FB6, FB7, FB8, FB9 | 0603 | 12 | FerriteBead | C1002
GPS1 | ublox_NEO | 1 | NEO-M9N-00B | C5119087
I1 | TerminalBlock_Phoenix_MKDS-1,5-16-5.08_1x16_P5.08mm_Horizontal | 1 | Reed Switches | C508906
I2 | TerminalBlock_Phoenix_MKDS-1,5-3-5.08_1x03_P5.08mm_Horizontal | 1 | WS281X Outputs | C8412
I3 | TerminalBlock_Phoenix_MKDS-1,5-3-5.08_1x03_P5.08mm_Horizontal | 1 | Temp Sensors | C8412
I4 | TerminalBlock_Phoenix_MKDS-1,5-2-5.08_1x02_P5.08mm_Horizontal | 1 | Water | C8445
I5 | TerminalBlock_Phoenix_MKDS-1,5-2-5.08_1x02_P5.08mm_Horizontal | 1 | Analog 1 | C8445
I6 | TerminalBlock_Phoenix_MKDS-1,5-2-5.08_1x02_P5.08mm_Horizontal | 1 | Analog 2 | C8445
J1 | U.FL_Hirose_U.FL-R-SMT-1_Vertical | 1 | Conn_Coaxial | C88373
J2 | TerminalBlock_Phoenix_MKDS-1,5-2-5.08_1x02_P5.08mm_Horizontal | 1 | 12VDC IN | C8445
K1, K2, K3, K4 | Relay_SPDT_SANYOU_SRD_Series_Form_C | 4 | Relay_SPDT | C35449
L1, L2 | L_SXN_SMDRI127 | 2 | 3.3uH | C24550
PI1 | PinSocket_2x20_P2.54mm_Vertical | 1 | Raspberry PI HAT | C132132
PWM1, PWM2, PWM3, PWM4 | TerminalBlock_Phoenix_MKDS-1,5-10-5.08_1x10_P5.08mm_Horizontal | 4 | LED Channels | C29173
Q1, Q10, Q11, Q12, Q17, Q18, Q19, Q2, Q20, Q3, Q4, Q5, Q6, Q7, Q8, Q9 | TO-252-2 | 16 | IRLB8721PBF | C99124
Q13, Q14, Q15, Q16 | TO-92_Inline | 4 | 2N7000 | C9114
R1, R2, R3, R4, R5, R6, R7 | 0805 | 7 | 220R | C17557
R10 | 0805 | 1 | 15.8K | C17468
R100, R103, R38, R41, R44, R47, R50, R53, R56, R59, R62, R65, R68, R71, R81, R85, R89, R93, R94, R97 | 0805 | 20 | 100R | C17408
R101, R104, R39, R42, R45, R48, R51, R54, R57, R60, R63, R66, R69, R72, R80, R84, R88, R92, R95, R98 | 0805 | 20 | 10K | C17414
R102, R105, R40, R43, R46, R49, R52, R55, R58, R61, R64, R67, R70, R73, R96, R99 | 0805 | 16 | 1K | C17513
R11 | 0805 | 1 | 1R | C25271
R12, R8, R9 | 0402 | 3 | 1K | C11702
R13 | 0805 | 1 | 115K | C158272
R14 | 0805 | 1 | 22.1K | C17552
R15 | 0805 | 1 | 2.2K | C17520
R16, R18, R20 | 0805 | 3 | 150R | C17471
R17, R19, R21 | 0805 | 3 | 470R | C17710
R22, R23, R24, R25, R26, R27, R28, R29, R30, R31, R32, R33, R34, R35, R36, R37 | 0805 | 16 | 4.7K | C17673
R74, R75 | 0805 | 2 | 33R | C17634
R76, R77 | 0402 | 2 | 10K | C60490
R78, R82, R86, R90 | 0805 | 4 | 330R | C17630
R79, R83, R87, R91 | 0603 | 4 | 1K | C5123612
RE1 | TerminalBlock_Phoenix_MKDS-3-5-5.08_1x05_P5.08mm_Horizontal | 1 | Relay 1 | C8423
RE2 | TerminalBlock_Phoenix_MKDS-3-5-5.08_1x05_P5.08mm_Horizontal | 1 | Relay 2 | C8423
RE3 | TerminalBlock_Phoenix_MKDS-3-5-5.08_1x05_P5.08mm_Horizontal | 1 | Relay 3 | C8423
RE4 | TerminalBlock_Phoenix_MKDS-3-5-5.08_1x05_P5.08mm_Horizontal | 1 | Relay 4 | C8423
RP? | raspberrypi_4 | 1 | Raspberry_Pi_2_3
SW1, SW3 | SW_PUSH_1P1T_6x3.5mm_H5.0_APEM_MJTP1250 | 2 | RESET | C500070
SW2, SW4 | SW_PUSH_1P1T_6x3.5mm_H5.0_APEM_MJTP1250 | 2 | BOOT | C500070
U1 | SOIC-8-1EP_3.9x4.9mm_P1.27mm_EP2.95x4.9mm_Mask2.71x3.4mm_ThermalVias | 1 | AP64501SP-13 | C2071517
U2, U3, U4, U5 | DIP-4_W7.62mm | 4 | PC817 | C5353

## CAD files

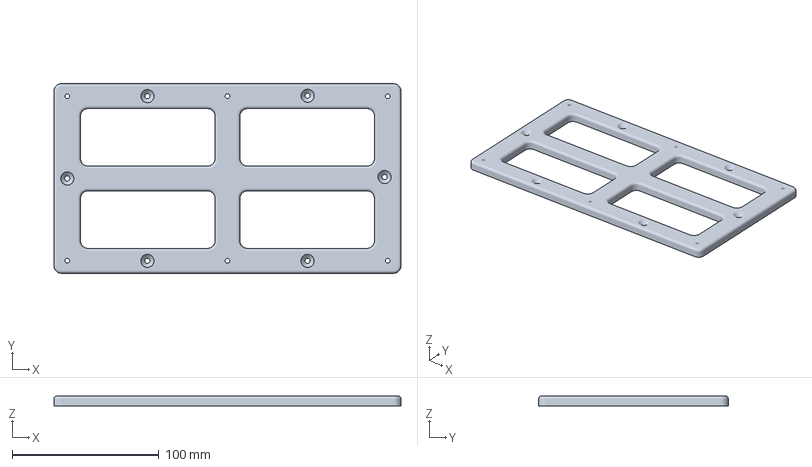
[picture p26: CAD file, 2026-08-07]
kicad/PCCS5 Bracket.3mf
236.1 x 129.0 x 7.00 mm

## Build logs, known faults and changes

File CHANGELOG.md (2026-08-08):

# Changelog

All notable changes to PCCS5 are documented in this file.

## [5.1.08082026] - 2026-08-08

### Added
- "Hardware offline" placeholder notice shown in the Lighting and Scenes grids when the ESP32 dimmer boards are disconnected
- Automatic hide/show of dashboard tiles based on connected-hardware status (`show-disconnected-tiles.js`, `home-module-visibility.js`)

### Changed
- Dashboard tile order reprioritized across all breakpoints so power and water lead, with settings/amenity tiles (appearance, Sonos) trailing
- GPS, Victron, PCCS Core, and System tiles updated to reflect degraded/offline hardware state

## [5.0.08082026] - 2026-08-08

### Added
- Initial release of the Pissmole Camper Control System (PCCS5)

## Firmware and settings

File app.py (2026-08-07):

"""PCCS5 — Flask + SocketIO bridge for lighting/relay control."""

from __future__ import annotations

import atexit
import logging
import os
import subprocess
import sys
import threading
from datetime import datetime
from urllib.parse import urlparse

from flask import Flask, Response, jsonify, render_template, request
from flask_cors import CORS
from flask_socketio import SocketIO, emit

from bridge.runtime import PCCSRuntime
from gps import get_gps_status, set_gps_module
from modules.config import config
from modules.gps import GPSModule
from modules.logger import setup_logging
from modules.phases import PhaseManager
from modules.sensors import SensorManager
from modules.toasts import ToastManager
from modules.ui_state import ConfigManager

import modules.toasts
from network import build_network_status
from sonos import get_sonos_status, set_muted, set_sonos_manager, set_transport, set_volume
from system import get_system_status, set_gps_module as set_system_gps, set_runtime, set_victron_module
from victron import get_power_status, set_victron_manager as set_power_victron
from weather import get_weather_status, set_gps_module as set_weather_gps
from wifi import (
    connect_wifi,
    disconnect_wifi,
    get_wifi_status,
    scan_wifi_networks,
    set_preferred_uplink,
)

logger = setup_logging(config)

if config.getboolean("logging", "suppress_werkzeug", fallback=True):
    logging.getLogger("werkzeug").setLevel(logging.WARNING)
if config.getboolean("logging", "suppress_engineio", fallback=True):
    logging.getLogger("engineio").setLevel(logging.WARNING)
if config.getboolean("logging", "suppress_socketio", fallback=True):
    logging.getLogger("socketio").setLevel(logging.WARNING)


def log_exception(exc_type, exc_value, exc_traceback):
    if issubclass(exc_type, KeyboardInterrupt):
        sys.__excepthook__(exc_type, exc_value, exc_traceback)
        return
    logger.critical("Unhandled exception", exc_info=(exc_type, exc_value, exc_traceback))


sys.excepthook = log_exception


def _patch_engineio_werkzeug_websocket() -> None:
    """Engine.IO hijacks the socket for WebSocket upgrades without calling WSGI start_response.

    Werkzeug then raises AssertionError: write() before start_response when the
    handler returns. Signal a dropped connection instead (same idea as gunicorn's
    StopIteration path in engineio's SimpleWebSocketWSGI).
    """
    from engineio.async_drivers import _websocket_wsgi as wswsgi

    if getattr(wswsgi.SimpleWebSocketWSGI, "_pccs5_werkzeug_patch", False):
        return

    _orig_call = wswsgi.SimpleWebSocketWSGI.__call__

    def __call__(self, environ, start_response):
        ret = _orig_call(self, environ, start_response)
        if getattr(getattr(self, "ws", None), "mode", None) == "werkzeug":
            raise ConnectionError("WebSocket connection handled outside WSGI")
        return ret

    wswsgi.SimpleWebSocketWSGI.__call__ = __call__
    wswsgi.SimpleWebSocketWSGI._pccs5_werkzeug_patch = True


_patch_engineio_werkzeug_websocket()

app = Flask(__name__)
app.config["SECRET_KEY"] = config.get("system", "secret_key", fallback="pccs5-secret")
CORS(app)
socketio = SocketIO(app, cors_allowed_origins="*", async_mode="threading")

debug_mode = config.getboolean("system", "debug", fallback=False)
if debug_mode:
    app.config["TEMPLATES_AUTO_RELOAD"] = True
    app.config["SEND_FILE_MAX_AGE_DEFAULT"] = 0

toast_manager = ToastManager(config, socketio)
modules.toasts.toast_manager = toast_manager

dark_mode_config = ConfigManager("active_dark_mode.json", {"mode": "dark", "manual": False})
_default_theme = config.get("ui", "default_theme", fallback="neuglass")
if _default_theme == "base":
    _default_theme = "neuglass"
theme_config = ConfigManager("active_theme.json", {"theme": _default_theme})
current_global_theme = theme_config.load()["theme"]

runtime = PCCSRuntime(config, socketio=socketio, dark_mode_config=dark_mode_config)
set_runtime(runtime)

gps_module = None
phase_manager = None
sensor_manager = None
victron_module = None
sonos_module = None
first_state_read_done = False
shutdown_event = threading.Event()
_cleanup_done = False


def _theme_sort_key(item: dict) -> tuple:
    name = item["name"].lower()
    return (0 if name.endswith("morphism") else 1, name)


def _extract_css_friendly_name(filepath: str, fallback: str) -> str:
    try:
        with open(filepath, encoding="utf-8") as handle:
            first = handle.readline().strip()
            if first.startswith("/*") and first.endswith("*/"):
                comment = first[2:-2].strip()
                if comment:
                    return comment
    except OSError:
        pass
    return fallback


def _network_status_payload() -> dict:
    start_time = getattr(app, "_start_time", None)
    return build_network_status(start_time)


def network_status_broadcaster() -> None:
    while not shutdown_event.is_set():
        try:
            socketio.emit("network_update", _network_status_payload())
        except Exception:
            pass
        if shutdown_event.wait(8.5):
            break

NAV_ITEMS = [
    {"id": "home", "label": "Home", "icon": "fa-house"},
    {"id": "lighting", "label": "Lighting", "icon": "fa-lightbulb"},
    {"id": "scenes", "label": "Scenes", "icon": "fa-wand-magic-sparkles"},
    {"id": "system", "label": "System", "icon": "fa-gear"},
]


@app.context_processor
def inject_nav():
    return {"nav_items": NAV_ITEMS}


@app.route("/")
def index():
    return render_template("index.html", active_page="home")


@app.route("/api/power")
def api_power():
    return jsonify(get_power_status())


@app.route("/api/victron")
def api_victron():
    if victron_module:
        return jsonify(victron_module.get_state())
    return jsonify({"stale": True, "shunt": {"configured": False}, "mppt": {"configured": False}})


@app.route("/api/gps")
def api_gps():
    return jsonify(get_gps_status())


@app.route("/api/system")
def api_system():
    return jsonify(get_system_status())


@app.route("/api/weather")
def api_weather():
    return jsonify(get_weather_status())


@app.route("/api/network")
def api_network():
    return jsonify(_network_status_payload())


@app.route("/api/themes")
def api_get_themes():
    themes, seen = [], set()
    themes_dir = os.path.join(app.static_folder, "css", "themes")
    if os.path.isdir(themes_dir):
        for filename in sorted(os.listdir(themes_dir)):
            if not filename.endswith(".css"):
                continue
            base = filename[:-4]
            if base in seen:
                continue
            seen.add(base)
            path = os.path.join(themes_dir, filename)
            fallback = base.replace("-", " ").replace("_", " ").title()
            themes.append({"file": base, "name": _extract_css_friendly_name(path, fallback)})
    themes.sort(key=_theme_sort_key)
    return jsonify({"themes": themes})


@app.route("/api/current-theme")
def api_get_current_theme():
    return jsonify({"theme": current_global_theme})


@app.route("/api/sonos")
def api_sonos():
    return jsonify(get_sonos_status())


@app.route("/api/sonos/transport", methods=["POST"])
def api_sonos_transport():
    payload = request.get_json(silent=True) or {}
    return jsonify(set_transport(str(payload.get("action", ""))))


@app.route("/api/sonos/volume", methods=["POST"])
def api_sonos_volume():
    payload = request.get_json(silent=True) or {}
    try:
        level = int(payload.get("level", 0))
    except (TypeError, ValueError):
        level = 0
    return jsonify(set_volume(level))


@app.route("/api/sonos/mute", methods=["POST"])
def api_sonos_mute():
    payload = request.get_json(silent=True) or {}
    return jsonify(set_muted(bool(payload.get("muted"))))


@app.route("/sonos-art")
def proxy_sonos_album_art():
    art_url = request.args.get("url")
    if not art_url:
        return "Missing url", 400
    try:
        import requests

        parsed = urlparse(art_url)
        if parsed.port != 1400:
            return "Invalid", 403
        resp = requests.get(art_url, timeout=10, stream=True)
        if resp.status_code != 200:
            return "Failed", resp.status_code
        return Response(
            resp.iter_content(8192),
            content_type=resp.headers.get("content-type", "image/jpeg"),
            headers={"Cache-Control": "public, max-age=7200"},
        )
    except Exception as e:
        logger.warning(f"Sonos art proxy: {e}")
        return "Error", 502


@app.route("/api/wifi")
def api_wifi():
    return jsonify(get_wifi_status())


@app.route("/api/wifi/scan", methods=["POST"])
def api_wifi_scan():
    return jsonify(scan_wifi_networks())


@app.route("/api/wifi/connect", methods=["POST"])
def api_wifi_connect():
    payload = request.get_json(silent=True) or {}
    password = payload.get("password")
    if password is not None:
        password = str(password)
    return jsonify(connect_wifi(str(payload.get("ssid", "")), password))


@app.route("/api/wifi/disconnect", methods=["POST"])
def api_wifi_disconnect():
    return jsonify(disconnect_wifi())


@app.route("/api/wifi/prefer", methods=["POST"])
def api_wifi_prefer():
    payload = request.get_json(silent=True) or {}
    prefer = payload.get("prefer") or payload.get("uplink") or ""
    return jsonify(set_preferred_uplink(str(prefer)))


def _apply_light_change(data, *, source: str = "socket"):
    if not data or "name" not in data:
        logger.warning(f"light_change ignored ({source}) — bad payload: {data!r}")
        return None
    name = data["name"]
    if name not in runtime.compiled.light_names:
        logger.warning(f"light_change ignored ({source}) — unknown light: {name}")
        return None
    try:
        target = max(0, min(100, int(data.get("brightness", 0))))
    except (TypeError, ValueError):
        logger.warning(f"light_change ignored ({source}) — invalid brightness: {data.get('brightness')!r}")
        return None
    mode = data.get("mode", "white") if name in runtime.compiled.rgb_lights else None
    runtime.set_light_intent(name, target, mode)
    return runtime.get_ui_state()


@app.route("/api/light", methods=["POST"])
def api_light_change():
    state = _apply_light_change(request.get_json(silent=True) or {}, source="http")
    if state is None:
        return jsonify({"ok": False}), 400
    return jsonify({"ok": True, "state": state})


@app.route("/api/relay", methods=["POST"])
def api_relay_change():
    data = request.get_json(silent=True) or {}
    name = data.get("name")
    if name not in runtime.compiled.relay_names:
        logger.warning(f"relay_change ignored (http) — unknown relay: {name}")
        return jsonify({"ok": False}), 400
    runtime.set_relay_intent(name, bool(data.get("on", False)))
    return jsonify({"ok": True})


@app.route("/api/explain")
def api_explain():
    return jsonify(runtime.get_explain_json())


@app.route("/api/scenes")
def api_get_scenes():
    scenes = dict(
        sorted(runtime.compiled.scenes.items(), key=lambda item: item[1].get("order", 999))
    )
    return jsonify({
        "scenes": [
            {
                "key": k,
                "name": d["name"],
                "icon": d["icon"],
                "description": d["description"],
                "all_off": d["all_off"],
            }
            for k, d in scenes.items()
        ]
    })


@app.route("/api/scene", methods=["POST"])
def api_set_scene():
    data = request.get_json(silent=True) or {}
    scene = data.get("scene")
    if not scene or scene not in runtime.compiled.scenes:
        return jsonify({"ok": False}), 400
    runtime.set_scene(scene)
    return jsonify({
        "ok": True,
        "state": runtime.get_ui_state(),
        "ramp_ms": runtime.compiled.scene_ramp_ms,
    })


@app.route("/api/lights")
def api_get_lights():
    return jsonify({
        "lights": runtime.get_frontend_config(),
        "state": runtime.get_ui_state(),
    })


@app.route("/api/reeds/force", methods=["POST"])
def api_force_reed():
    data = request.get_json(silent=True) or {}
    name = data.get("name")
    if name is None:
        return jsonify({"ok": False, "error": "name required"}), 400
    state = runtime.force_reed(name, data.get("closed"))
    return jsonify({
        "ok": True,
        "state": state,
        "ramp_ms": state.get("_ramp_ms") or runtime.compiled.reed_ramp_ms,
        "reeds": runtime.get_reed_diag_json(),
        "effective": runtime.effective_reed_states(),
    })


@app.route("/api/reeds")
def api_get_reeds():
    diag = runtime.get_reed_diag_json()
    return jsonify({
        "reeds": runtime.get_reeds_frontend_config(),
        "states": runtime.effective_reed_states(),
        "raw": diag.get("states", {}),
        "forced": diag.get("forced", {}),
    })


def _screen_frontend_item(name: str, conf: dict, conn: dict | None = None) -> dict:
    """Build one screen record for the system tile."""
    from actuators.screens import brightness_is_adjustable

    observed_pct = 0
    if runtime.screen_actuator:
        observed_pct = runtime.screen_actuator._observed.get(name, 0)

    adjustable = brightness_is_adjustable(conf.get("brightness_path") or "")

    item = {
        "name": name,
        "label": conf.get("friendly", name),
        "icon": conf.get("icon", "fa-display"),
        "online": False,
        "latency": None,
        "on": observed_pct > 0,
        "brightness": None,
        "brightness_pct": observed_pct if observed_pct > 0 else None,
        "brightness_adjustable": adjustable,
        "ssh_passwordless": False,
        "ssh_error": None,
    }
    if conn:
        if conn.get("on") is not None:
            item["on"] = conn["on"]
        item["online"] = conn.get("online", False)
        item["brightness"] = conn.get("brightness")
        if conn.get("brightness_pct") is not None:
            item["brightness_pct"] = conn["brightness_pct"]
        item["ssh_passwordless"] = conn.get("ssh_passwordless", False)
        item["ssh_error"] = conn.get("ssh_error")
    return item


def _screens_list(*, probe: bool = False) -> list:
    if not runtime.screen_actuator:
        return []
    screens = []
    for name, conf in runtime.compiled.screens.items():
        conn = None
        if probe:
            conn = runtime.screen_actuator.test_connectivity(name)
        screens.append(_screen_frontend_item(name, conf, conn))
    return screens


@app.route("/api/screens")
def api_get_screens():
    return jsonify({"screens": _screens_list()})


@app.route("/api/screens/status")
def api_get_screens_status():
    return jsonify({"screens": _screens_list(probe=True)})


def _cleanup_best_effort(timeout_s: float = 10) -> None:
    """Run cleanup without blocking shutdown if hardware teardown hangs."""
    try:
        worker = threading.Thread(target=cleanup, daemon=True, name="shutdown-cleanup")
        worker.start()
        worker.join(timeout=timeout_s)
        if worker.is_alive():
            logger.warning("Shutdown cleanup did not finish within %.0fs", timeout_s)
    except Exception as e:
        logger.error(f"Shutdown cleanup error: {e}")


def _issue_host_shutdown() -> bool:
    """Schedule host power-off. Never call this in tests without mocking."""
    try:
        subprocess.Popen(
            ["sudo", "-n", "shutdown", "-h", "now"],
            stdout=subprocess.DEVNULL,
            stderr=subprocess.DEVNULL,
            start_new_session=True,
        )
        logger.warning("Host shutdown command issued")
        return True
    except Exception as e:
        logger.error(f"Host shutdown failed: {e}")
        return False


@app.route("/api/system/shutdown", methods=["POST"])
def api_system_shutdown():
    """Shut down remote touchscreens, then this Pi."""
    logger.warning("System shutdown requested via API")

    def _shutdown_sequence():
        import time

        # Screens first: host power-off tears down the network and kills SSH.
        # shutdown_all() blocks until each remote attempt finishes (or times out).
        if runtime.screen_actuator:
            try:
                runtime.screen_actuator.shutdown_all()
            except Exception as e:
                logger.warning("Screen shutdown phase failed: %s", e)

        # Issue host shutdown before cleanup — GPIO factory.close() can hang
        # indefinitely and previously prevented shutdown from ever running.
        if not _issue_host_shutdown():
            return

        time.sleep(2)
        _cleanup_best_effort()

    threading.Thread(target=_shutdown_sequence, daemon=True, name="shutdown-host").start()
    return jsonify({"ok": True, "message": "Shutting down…"})


@app.route("/api/phases")
def api_get_phases():
    if not phase_manager:
        return jsonify({"phase": None, "forced": False, "times": {}})
    times = {}
    try:
        times = phase_manager.get_phase_times()
    except Exception:
        pass
    return jsonify({
        "phase": phase_manager.get_phase(),
        "forced": phase_manager.is_forced(),
        "times": times,
    })


@app.route("/api/sensors")
def api_get_sensors():
    if not sensor_manager:
        return jsonify({"source": "unavailable"})
    reading = getattr(sensor_manager, "last_reading", None) or {}
    payload = dict(reading)
    payload["source"] = "live" if reading else "waiting"
    return jsonify(payload)


@app.route("/api/dark-mode")
def api_get_dark_mode():
    if not phase_manager:
        return jsonify({"mode": "dark", "manual": False})
    return jsonify({
        "mode": phase_manager.get_current_dark_mode(),
        "manual": phase_manager.manual_dark_mode is not None,
    })


@socketio.on("light_change")
def handle_light_change(data):
    state = _apply_light_change(data, source="socket")
    if state is not None:
        emit("state_update", state)


@socketio.on("relay_change")
def handle_relay_change(data):
    name = data.get("name")
    if name not in runtime.compiled.relay_names:
        logger.warning(f"relay_change ignored — unknown relay: {name}")
        return
    runtime.set_relay_intent(name, bool(data.get("on", False)))


@socketio.on("get_reeds")
def handle_get_reeds():
    emit("reed_update", {"states": runtime.effective_reed_states()})


@socketio.on("force_reed")
def handle_force_reed(data):
    name = data.get("name")
    if name is None:
        return
    runtime.force_reed(name, data.get("closed"))


@socketio.on("set_scene")
def handle_set_scene(data):
    scene = data.get("scene")
    if not scene or scene not in runtime.compiled.scenes:
        return
    runtime.set_scene(scene)
    emit("state_update", runtime.get_ui_state(), broadcast=True)


@socketio.on("force_phase")
def handle_force_phase(data):
    runtime.force_phase(data.get("phase"))


@socketio.on("get_reeds_diag")
def handle_get_reeds_diag():
    emit("reed_diag_update", runtime.get_reed_diag_json())


@socketio.on("set_gps_simulation")
def handle_gps_simulation(data):
    if not gps_module:
        return
    payload = data or {}
    if "no_hardware" in payload and hasattr(gps_module, "set_no_hardware_simulation"):
        gps_module.set_no_hardware_simulation(bool(payload.get("no_hardware")))
    if "no_fix" in payload and hasattr(gps_module, "set_no_fix_simulation"):
        gps_module.set_no_fix_simulation(bool(payload.get("no_fix")))


@socketio.on("screen_manual_toggle")
def handle_screen_manual_toggle(data):
    """Direct hardware command only — no sticky screen intents (reed policy wins)."""
    if not runtime.screen_actuator:
        return
    name = data.get("name")
    if not name:
        return

    def _apply_screen_level(level: int):
        level = max(0, min(100, int(level)))
        # Align commanded cache so the next reed reconcile re-sends policy cleanly
        if hasattr(runtime.reconciler, "_commanded_screens"):
            runtime.reconciler._commanded_screens[name] = level
        runtime.screen_actuator.manual_toggle(name, brightness_pct=level)
        runtime._emit_screens_observed([name])

    brightness = data.get("brightness_pct")
    if brightness is not None:
        try:
            brightness = max(0, min(100, int(brightness)))
        except (TypeError, ValueError):
            return
        _apply_screen_level(brightness)
        return

    on = data.get("on")
    if on:
        from engine.precedence import resolve_screen

        screen = runtime.compiled.screens.get(name)
        # Use phase level when reed allows; if reed is closed (policy 0), still
        # send a one-shot wake using day level — next reed reconcile restores policy.
        level = 100
        if screen:
            level = resolve_screen(screen, runtime.world.snapshot(), runtime.compiled)
            if level <= 0:
                levels = screen.get("phase_brightness") or {}
                level = int(levels.get("day") or max(levels.values(), default=100) or 100)
        _apply_screen_level(level)
        return
    _apply_screen_level(0)


@socketio.on("set_global_dark_mode")
def handle_set_global_dark_mode(data):
    mode = data.get("mode")
    if mode not in ("dark", "light"):
        return
    if phase_manager:
        phase_manager.set_manual_dark_mode(mode)
    emit("global_dark_mode_update", {"mode": mode, "manual": True}, broadcast=True)


@socketio.on("set_global_theme")
def handle_set_global_theme(data):
    global current_global_theme
    theme = data.get("theme")
    if not theme:
        return
    current_global_theme = theme
    theme_config.save({"theme": theme})
    emit("global_theme_update", {"theme": theme}, broadcast=True)


@socketio.on("get_network_status")
def handle_get_network_status():
    emit("network_update", _network_status_payload())
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

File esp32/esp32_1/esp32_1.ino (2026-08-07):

/*
 * PCCS5 — ESP32-1 (ESP32-S3-WROOM-1U)
 *
 * Pi link: Pi UART3 GPIO 4 (TX) / 5 (RX) ↔ this ESP UART1 GPIO 17 (RX) / 18 (TX).
 *
 * PWM (module GPIO): 4–11  (silk 1-4 … 1-11)
 *   1-4 kitchen panel white, 1-5 red, 1-6 green
 *   1-7 kitchen bench, 1-8 storage, 1-9 rear drawer
 *   1-10 / 1-11 spare
 * Analog: GPIO 1 (silk 1-1) water tank sender (150 Ω to 3V3)
 *
 * Module: ESP32-S3-WROOM-1U. Upload: see esp32/README.md
 */

#define PCCS_ESP_ID 1
#define PCCS_PWM_PINS {4, 5, 6, 7, 8, 9, 10, 11}
#define PCCS_ANALOG_PINS {1}

// Host UART1 to the Pi (both ESPs use the same pins).
#define PCCS_HOST_RX 17
#define PCCS_HOST_TX 18

#include "PccsEspFirmware.h"

void setup() {
  pccsSetup();
}

void loop() {
  pccsLoop();
}

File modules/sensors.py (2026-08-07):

# modules/sensors.py
import threading
import time
import logging
import glob
import os
import struct
import subprocess

logger = logging.getLogger("pccs")
logger.propagate = True

W1_DEVICES_DIR = "/sys/bus/w1/devices/"
W1_DT_BASE = "/sys/firmware/devicetree/base"


class SensorManager:
    def __init__(self, config, send_command_func, socketio):
        self.config = config
        self.send_command = send_command_func
        self.socketio = socketio
        self.running = False
        self.thread = None

        # Load 1-Wire kernel modules (best effort). On modern Raspberry Pi OS these
        # are usually loaded automatically by dtoverlay=w1-gpio in config.txt.
        # Running as non-root user will cause "Operation not permitted", which is harmless.
        try:
            subprocess.run(['modprobe', 'w1-gpio'], capture_output=True, check=False)
            subprocess.run(['modprobe', 'w1-therm'], capture_output=True, check=False)
        except Exception:
            pass
        time.sleep(0.5)

        # ====================== CALIBRATION FROM CONFIG ======================
        # Divider: 3V3 -- R_pullup (150 Ω) -- sense -- R_sender -- GND
        # Sender: empty ≈ 240 Ω, full ≈ 33 Ω (standard automotive fuel sender).
        self.WATER_R_EMPTY = config.getfloat('sensors', 'water_resistance_empty', fallback=240.0)
        self.WATER_R_FULL = config.getfloat('sensors', 'water_resistance_full', fallback=33.0)
        self.WATER_R_PULLUP = config.getfloat('sensors', 'water_pullup_ohms', fallback=150.0)
        # ESP32-S3 ADC is 12-bit (0..4095) unless firmware remaps to 10-bit.
        self.WATER_ADC_MAX = config.getfloat('sensors', 'water_adc_max', fallback=4095.0)
        self.WATER_CAPACITY_LITRES = config.getfloat('tanks', 'water_litres', fallback=0)

        # Water level on ESP32-1 module GPIO (silk 1-1); ANALOG <gpio> protocol.
        self.WATER_PIN = config.getint('esp32 analog', 'water_pin')
        self.WATER_ESP = config.getint('esp32 analog', 'water_esp', fallback=1)

        # Dual 1-Wire buses (PCCS PCB): GPIO4 outside+fridge, GPIO3 freezer.
        # Must match dtoverlay=w1-gpio,gpiopin=N lines in /boot/firmware/config.txt.
        self.OUTSIDE_BUS_GPIO = config.getint('sensors', 'outside_temp_bus_gpio', fallback=4)
        self.FRIDGE_BUS_GPIO = config.getint('sensors', 'fridge_temp_bus_gpio', fallback=4)
        self.FREEZER_BUS_GPIO = config.getint('sensors', 'freezer_temp_bus_gpio', fallback=3)

        # 1-Wire DS18B20 sensor IDs (folder names under /sys/bus/w1/devices/, e.g. "28-3ce1d4435d5a")
        # Leave blank to auto-detect first available 28* device on that role's bus.
        self.OUTSIDE_TEMP_ID = (config.get('sensors', 'outside_temp_sensor', fallback='') or '').strip() or None
        self.FRIDGE_TEMP_ID = (config.get('sensors', 'fridge_temp_sensor', fallback='') or '').strip() or None
        self.FREEZER_TEMP_ID = (config.get('sensors', 'freezer_temp_sensor', fallback='') or '').strip() or None
        # ========================================================

        self._last_analog_warn = 0.0
        self._last_vcc_warn = 0.0
        self._last_missing_warn: dict[str, float] = {}
        self.last_reading: dict = {}

        # gpio_pin -> sysfs master path (e.g. /sys/devices/w1_bus_master1)
        self._w1_masters_by_gpio = self._discover_w1_masters_by_gpio()
        expected_gpios = sorted({self.OUTSIDE_BUS_GPIO, self.FRIDGE_BUS_GPIO, self.FREEZER_BUS_GPIO})
        found = sorted(self._w1_masters_by_gpio.keys())
        logger.info(
            "🔋 1-Wire buses: expected GPIO %s → masters on GPIO %s",
            expected_gpios,
            found if found else "none yet",
        )
        for gpio in expected_gpios:
            if gpio not in self._w1_masters_by_gpio:
                logger.warning(
                    "   🌡️ No w1 master for GPIO %s — add "
                    "dtoverlay=w1-gpio,gpiopin=%s to /boot/firmware/config.txt and reboot",
                    gpio,
                    gpio,
                )

        configured = []
        if self.OUTSIDE_TEMP_ID:
            configured.append(f"outside={self.OUTSIDE_TEMP_ID}@GPIO{self.OUTSIDE_BUS_GPIO}")
        else:
            configured.append(f"outside=auto@GPIO{self.OUTSIDE_BUS_GPIO}")
        if self.FRIDGE_TEMP_ID:
            configured.append(f"fridge={self.FRIDGE_TEMP_ID}@GPIO{self.FRIDGE_BUS_GPIO}")
        else:
            configured.append(f"fridge=none@GPIO{self.FRIDGE_BUS_GPIO}")
        if self.FREEZER_TEMP_ID:
            configured.append(f"freezer={self.FREEZER_TEMP_ID}@GPIO{self.FREEZER_BUS_GPIO}")
        else:
            configured.append(f"freezer=none@GPIO{self.FREEZER_BUS_GPIO}")
        logger.info("🔋 1-Wire temp sensors configured: %s", ", ".join(configured))

        logger.info("🔋 SensorManager initialized")

    @staticmethod
    def _discover_w1_masters_by_gpio() -> dict[int, str]:
        """Map each w1-gpio overlay pin to its sysfs master directory.

        Raspberry Pi device-tree nodes look like /proc/device-tree/onewire@N
        with a 3-cell `gpios` property: <phandle pin flags>. Platform devices
        expose of_node → those DT nodes, and w1 registers them as w1_bus_master*.
        """
        gpio_to_dt: dict[int, str] = {}
        if os.path.isdir(W1_DT_BASE):
            try:
                for name in os.listdir(W1_DT_BASE):
                    if not name.startswith("onewire"):
                        continue
                    gpios_path = os.path.join(W1_DT_BASE, name, "gpios")
                    if not os.path.isfile(gpios_path):
                        continue
                    try:
                        with open(gpios_path, "rb") as fh:
                            data = fh.read()
                        if len(data) >= 12:
                            pin = struct.unpack(">I", data[4:8])[0]
                            gpio_to_dt[pin] = os.path.realpath(os.path.join(W1_DT_BASE, name))
                    except OSError:
                        continue
            except OSError:
                pass

        masters: dict[int, str] = {}
        for master in sorted(glob.glob("/sys/devices/w1_bus_master*")):
            of_node = os.path.join(master, "of_node")
            if not os.path.exists(of_node):
                continue
            try:
                real = os.path.realpath(of_node)
            except OSError:
                continue
            for gpio, dt_path in gpio_to_dt.items():
                if real == dt_path or real.endswith(os.path.basename(dt_path)):
                    masters[gpio] = master
                    break
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
